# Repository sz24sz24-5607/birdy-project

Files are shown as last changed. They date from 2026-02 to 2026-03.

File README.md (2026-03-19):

<p align="center">
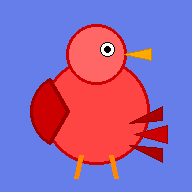
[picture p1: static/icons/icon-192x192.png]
Birdy Logo
  
</p>

<h1 align="center">Birdy - Smart Bird Feeder</h1>

<p align="center">
  <strong>AI-powered bird species identification on a Raspberry Pi 5</strong>
</p>

<p align="center">
  <a href="#features">Features</a> &bull;
  <a href="#hardware">Hardware</a> &bull;
  <a href="#architecture">Architecture</a> &bull;
  <a href="#installation">Installation</a> &bull;
  <a href="#configuration">Configuration</a> &bull;
  <a href="#home-assistant">Home Assistant</a>
</p>

---

Birdy turns a regular bird feeder into an intelligent monitoring station. A PIR sensor detects motion, triggers a camera recording, and a TensorFlow Lite model identifies the bird species in real time - all running locally on a Raspberry Pi 5 with no cloud dependency.

## Features

- **Real-time Bird Detection** - PIR motion sensor triggers dynamic video recording (up to 30s) at 720p/15fps
- **ML Species Identification** - TensorFlow Lite classifier identifies bird species in ~50-100ms
- **Regional Species Filter** - Swiss Mittelland allowlist (151 species) prevents implausible detections like Cardinals or Cockatoos
- **Web Dashboard** - Responsive Django web app with live stats, photo gallery, and video playback
- **Home Assistant Integration** - MQTT auto-discovery for feed weight, species, and visit counters
- **Weight Monitoring** - HX711 load cell tracks food level with automatic drift compensation
- **PWA Support** - Install as a native app on your phone
- **USB Media Storage** - Photos and videos stored on external USB drive
- **Statistics** - Daily, monthly, and yearly visit tracking per species

## Hardware

| Component | Model | GPIO |
| --- | --- | --- |
| Single Board Computer | Raspberry Pi 5 | - |
| Camera | Pi Camera Module | CSI |
| Motion Sensor | HC-SR501 PIR | GPIO 17 |
| Weight Sensor | HX711 + Load Cell | GPIO 5 (DT), GPIO 6 (SCK) |
| Storage | USB Drive mounted at `/mnt/birdy_storage` | USB |

## Architecture

```
PIR Trigger ──> Video Recording ──> Frame Extraction ──> ML Classification
   (GPIO 17)     (rpicam-vid)         (ffmpeg)           (TF Lite)
                                                             │
                    ┌────────────────────────────────────────┘
                    ▼
              ┌──────────┐     ┌──────────────┐     ┌─────────────┐
              │PostgreSQL │     │ MQTT Publish  │     │  Web Dashboard│
              │  Storage  │     │Home Assistant │     │  (Gunicorn)   │
              └──────────┘     └──────────────┘     └─────────────┘
```

### Tech Stack

| Layer | Technology |
| --- | --- |
| Web Framework | Django 5.0, Django REST Framework |
| Database | PostgreSQL 12 |
| Task Queue | Celery + Redis |
| ML Inference | TensorFlow Lite (iNaturalist bird model) |
| Video Encoding  | H.264 via rpicam-vid |
| WSGI Server | Gunicorn |
| Home Automation | MQTT (paho-mqtt) |
| Camera | picamera2 |

## Installation

### Prerequisites

- Raspberry Pi 5 with Raspberry Pi OS (64-bit)
- Python 3.13+
- PostgreSQL, Redis
- Pi Camera Module, HC-SR501 PIR sensor, HX711 weight sensor

### Setup

```bash
# Clone the repository
git clone https://github.com/sz24sz24-5607/birdy-project.git
cd birdy-project

# Create virtual environment
python3 -m venv venv
source venv/bin/activate

# Install dependencies
pip install -r requirements.txt

# Configure environment
cp .env.example .env
# Edit .env with your credentials

# Setup database
python manage.py migrate
python manage.py createsuperuser

# Collect static files
python manage.py collectstatic

# Calibrate weight sensor
python manage.py calibrate_weight
```

### Running

**Development:**
```bash
./start_dev.sh
```

**Production (systemd):**
```bash
# Copy service files
sudo cp systemd/*.service /etc/systemd/system/
sudo systemctl daemon-reload

# Enable and start all services
sudo systemctl enable --now birdy-gunicorn
sudo systemctl enable --now birdy-celery-worker
sudo systemctl enable --now birdy-celery-beat
sudo systemctl enable --now birdy-detection
```

## Configuration

All settings are in `birdy_config/settings.py`. Key parameters:

```python
BIRDY_SETTINGS = {
    'CAMERA_RESOLUTION': (1280, 720),
    'CAMERA_FRAMERATE': 15,
    'RECORDING_DURATION_SECONDS': 4,         # Fallback static duration
    'MAX_RECORDING_DURATION_SECONDS': 30,    # Dynamic recording max
    'PIR_ABSENCE_THRESHOLD_SECONDS': 3,      # PIR LOW for Xs → stop recording
    'VISIT_CONTINUATION_WINDOW_SECONDS': 300, # Same species within 5min = same visit
    'MIN_CONFIDENCE_THRESHOLD': 0.7,         # Display threshold
    'MIN_CONFIDENCE_SPECIES': 0.5,           # Valid visit threshold
    'BIRD_DETECTOR_ENABLED': True,           # SSD MobileNet V2 size/position filter
    'MIN_BIRD_COVERAGE': 0.05,               # Min bird bbox area (5% of frame)
}
```

Sensitive values (DB password, MQTT credentials, secret key) are loaded from `.env`.

## Home Assistant

Birdy publishes to MQTT with Home Assistant auto-discovery:

| Entity | Topic | Description |
| --- | --- | --- |
| Feed Weight | `birdy/feed/weight` | Current food weight (grams) |
| Bird Detected | `birdy/bird/detected` | Binary motion sensor |
| Last Species  | `birdy/bird/species`  | Last identified species |
| Visits Today  | `birdy/stats/today` | Daily visit counter |

## Detection Pipeline

1. PIR sensor triggers on motion
2. Camera records video dynamically (H.264, 720p): stops when PIR LOW for 3s, max 30s
3. Frames extracted proportionally via ffmpeg (2fps, min 8): e.g. 15s → 30 frames
4. Bird Size/Position Filter (SSD MobileNet V2 COCO): frames without a sufficiently large
   bird in the feeder area are discarded (fail-open: if all rejected, all frames are kept)
5. TensorFlow Lite classifies remaining frames (~50-100ms per frame)
   - Only species from `ml_models/swiss_midland_allowlist.txt` are considered (151 Swiss Mittelland species)
   - The species with the highest score among allowed species wins per frame
6. Frame with highest non-background confidence is selected as the best frame
7. If no valid bird detected (confidence < 50% or all frames = background): video deleted, no DB entry
8. Visit deduplication: same species within 5 minutes → `is_new_visit=False`, statistics not inflated
9. Results stored in PostgreSQL with best photo + video
10. MQTT notification sent to Home Assistant
11. Web dashboard updates automatically

### Regional Species Filter

The global iNaturalist model covers ~964 bird species worldwide. Without filtering, implausible
species were regularly detected (Northern Cardinal, Monk Parakeet, Galah, Kea, etc.).

The allowlist `ml_models/swiss_midland_allowlist.txt` restricts detections to **151 species**
plausible for the Swiss Mittelland — resident birds, common migrants, and waterbirds. The file
uses scientific names and can be freely extended. Restart `birdy-detection` after changes.

| Allowlist groups  | Examples |
| --- | --- |
| Songbirds | Robin, Blackbird, Tits, Finches, Buntings, Sparrows |
| Swallows / Swifts | Barn Swallow, House Martin, Common Swift |
| Woodpeckers | Great Spotted, Green Woodpecker |
| Pigeons | Wood Pigeon, Collared Dove |
| Owls | Barn Owl, Little Owl, Long-eared Owl |
| Raptors | Buzzard, Kestrel, Sparrowhawk, Red Kite |
| Corvids | Magpie, Jay, Jackdaw, Rook, Raven |
| Waterbirds | Mallard, Coot, Grey Heron, Cormorant |
| Swans & Geese | Mute Swan, Greylag Goose, Egyptian Goose |

## Mechanical Construction

The birdhouse enclosure is a hybrid construction with 3D-printed and CNC-milled parts. All source files and manufacturing data are in the `mechanic/` folder.

<p align="center">
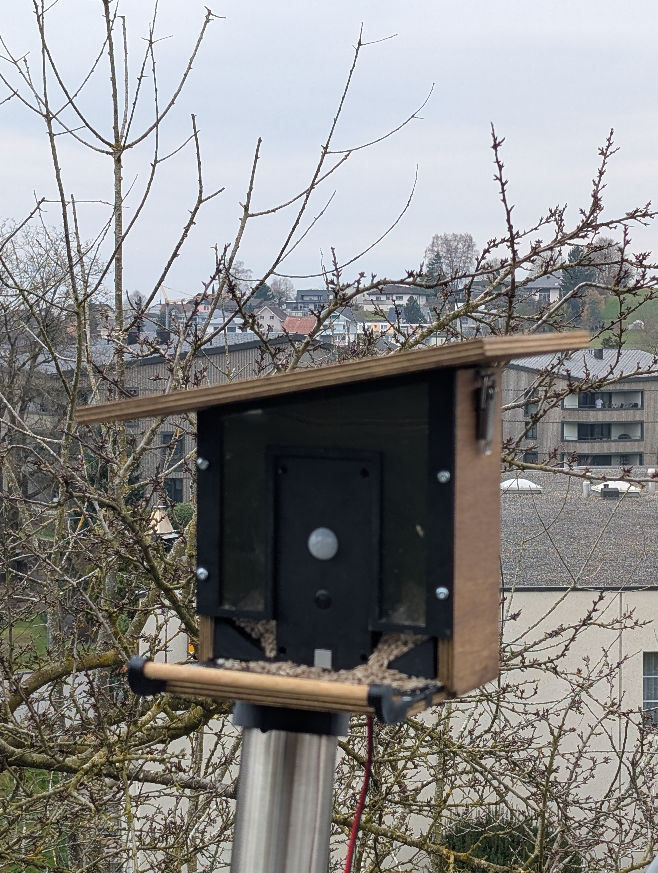
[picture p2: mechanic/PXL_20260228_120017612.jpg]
Finished Birdy birdhouse mounted on a pole
  
</p>

### 3D-Printed Parts (FDM)

| File | Description |
| --- | --- |
| `box_top.stl` / `box_bottom.stl` | Electronics enclosure (Raspberry Pi, camera) |
| `feeder_plate.stl` | Seed tray |
| `frame_left.stl` / `frame_right.stl` | Side frames |
| `bar_left.stl` / `bar_right.stl` | Mounting bars |
| `pole_mount.stl` / `pole_mount_2.stl` | Pole/post mounting bracket |
| `weight_main.stl` / `weight_left.stl` / `weight_right.stl` | Weight sensor housing |
| `konstruktion.skp` | SketchUp source file (full assembly) |

### CNC-Milled Parts (Wood) – `mechanic/mill/`

| File | Description |
| --- | --- |
| `back.stl` / `base.stl` / `left.stl` / `right.stl` | Wooden wall panels |
| `roof.stl` / `window.stl` | Roof and window panel |
| `*.E12` | Estlcam CNC project files |
| `m_*.gcode` | G-code toolpaths for CNC mill |

## Project Structure

```
birdy_project/
├── birdy_config/        # Django project settings & main views
├── sensors/             # Sensor models & management commands
├── species/             # Bird species models & statistics
├── media_manager/       # Photo & video models
├── homeassistant/       # MQTT client & HA integration
├── api/                 # REST API (DRF)
├── hardware/            # Camera, PIR, weight sensor drivers
├── services/            # Bird detection service
├── ml_models/           # TFLite model & label files
├── templates/           # Django HTML templates
├── static/              # CSS, icons, PWA manifest
├── systemd/             # Service files for production
└── mechanic/            # Birdhouse construction files (STL, SketchUp, G-code)
    └── mill/            # CNC milling files (Estlcam, G-code)
```

## Example Detections

<p align="center">
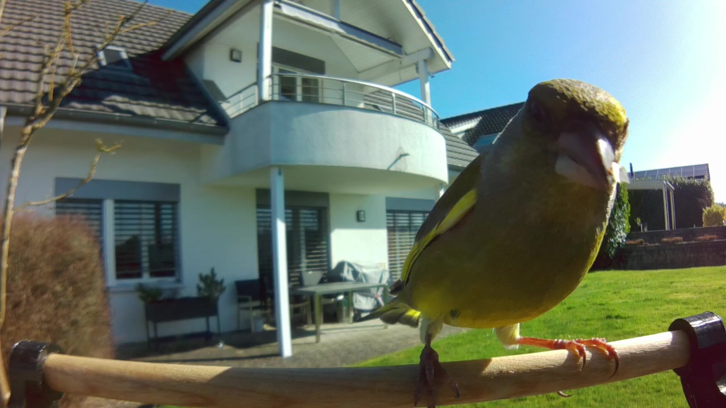
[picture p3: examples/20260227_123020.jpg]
Grünfink (European Greenfinch)
  
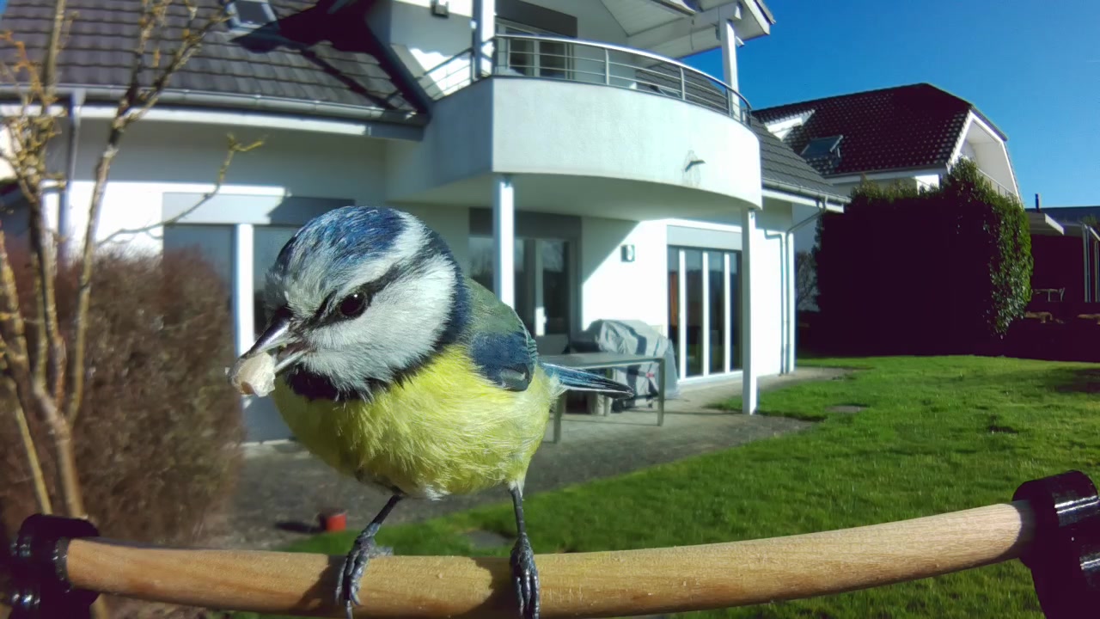
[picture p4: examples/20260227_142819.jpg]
Blaumeise (Blue Tit)
  
</p>
<p align="center">
  <em>Left: European Greenfinch &nbsp;|&nbsp; Right: Blue Tit picking up a seed</em>
</p>

## License

This project is open source. Feel free to build your own smart bird feeder!

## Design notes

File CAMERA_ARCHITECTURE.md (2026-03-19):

# Kamera-Architektur - Wichtige Hinweise

## Problem: Kamera-Zugriff über Prozessgrenzen

### Ursprüngliches Design (NICHT FUNKTIONSFÄHIG)
1. `start_birdy` initialisiert Kamera
2. PIR Motion Event triggert → `process_bird_detection.delay()` (Celery Task)
3. Celery Worker führt Task aus → **FEHLER**: Kamera nicht verfügbar!

### Warum das nicht funktioniert
- **Singleton funktioniert nur pro Prozess**: `_camera_worker_instance` ist in jedem Python-Prozess separate Variable
- **start_birdy Prozess**: Hat Camera Worker mit Kamera-Zugriff
- **Celery Worker Prozess**: Erstellt NEUEN Camera Worker ohne Kamera-Zugriff
- **Fehler**: `Camera not initialized (should be initialized by start_birdy)`

## Aktuelle Lösung: Thread-basierte Verarbeitung mit Recording Lock

### Architektur
1. `start_birdy` initialisiert Kamera, PIR-Sensor und Detection Service
2. PIR Motion Event triggert → `detection_service.handle_motion_detected(pir_event)`
3. `handle_motion_detected()` prüft `_recording_lock`: falls gesperrt → PIR-Trigger ignorieren
4. Falls frei → **Detection-Thread starten** (daemon=False, läuft bis zum Ende)
5. Verarbeitung läuft im **gleichen Prozess** wie start_birdy → Kamera verfügbar ✓
6. Thread belegt `_recording_lock` für gesamte Aufnahme + Klassifikation

### Code
In `services/bird_detection.py`:
```python
def handle_motion_detected(self, pir_event):
    # Wenn gerade eine Aufnahme läuft: PIR-Trigger ignorieren
    if self._recording_lock.locked():
        logger.debug("Recording already in progress – PIR trigger ignored")
        return

    # Detection in separatem Thread (PIR-Monitoring blockiert nicht)
    detection_thread = threading.Thread(
        target=self.process_detection,
        args=(pir_event.id,),
        daemon=False,
        name=f"BirdDetection-{pir_event.id}"
    )
    detection_thread.start()
```

### Vorteile
- ✓ Kamera-Zugriff funktioniert
- ✓ PIR-Monitoring wird während der Aufnahme **nicht blockiert**
- ✓ `_recording_lock` verhindert parallele Aufnahmen sauber
- ✓ Neue PIR-Trigger während laufender Aufnahme werden ignoriert
- ✓ Passt zur Hardware-Einschränkung (nur 1 Kamera)

### Dynamische Aufnahmedauer

Statt fixer 4s nutzt `record_video_dynamic()` den PIR-Status:
- Startet rpicam-vid als Hintergrundprozess (`subprocess.Popen`)
- Überwacht PIR alle 200ms: PIR LOW für ≥ `PIR_ABSENCE_THRESHOLD_SECONDS` (3s) → Aufnahme stoppen
- Sicherheitsnetz: max. `MAX_RECORDING_DURATION_SECONDS` (30s)
- Gibt `(mp4_path, actual_duration_seconds)` zurück

### Recording Lock Flow

```
PIR HIGH → handle_motion_detected()
  → _recording_lock.locked()? → TRUE  → Trigger ignoriert (Aufnahme läuft bereits)
                               → FALSE → Detection-Thread starten

Detection-Thread:
  with _recording_lock:          ← Lock belegen
    record_video_dynamic()       ← PIR überwachen, dynamisch stoppen (bis 30s)
    extract_candidate_frames()   ← Proportional (2fps, min 8 Frames)
    BirdSizeDetector filter      ← Frames ohne vollständigen Vogel verwerfen
    Alle Frames klassifizieren   ← Bestes Frame wählen
    BirdDetection speichern      ← is_new_visit Deduplication
                                 ← Lock freigeben → bereit für nächsten Besuch
```

## Celery Task Status

Der Celery Task `process_bird_detection` existiert noch, wird aber **NICHT verwendet**:
```python
@shared_task
def process_bird_detection(pir_event_id):
    """
    HINWEIS: Dieser Task wird aktuell NICHT verwendet!
    Grund: Kamera läuft nur in start_birdy Prozess, Celery Worker hat keinen Zugriff.
    """
    logger.warning("process_bird_detection task called - but detection should run in start_birdy!")
    pass
```

Der Task bleibt für potenzielle zukünftige Verwendung (z.B. Re-Processing von bereits aufgenommenen Videos).

## Celery Worker Konfiguration

Die `bird_detection` Queue-Konfiguration bleibt bestehen:
- `celery.py`: Task-Routing für `services.bird_detection.process_bird_detection`
- `settings.py`: Queue-Definition mit `bird_detection` und `default`

**Diese Konfiguration schadet nicht**, sie ist einfach inaktiv, da der Task nicht aufgerufen wird.

## Alternative Lösungen (NICHT implementiert)

### Option 1: Shared Camera Service via IPC
- Camera Worker als eigenständiger Service (z.B. Socket/Redis)
- Alle Prozesse kommunizieren über IPC
- **Zu komplex** für dieses Projekt

### Option 2: Video-Aufnahme und Processing trennen
- start_birdy: Nur Video aufnehmen, in DB speichern
- Celery Task: Nur Frame-Extraktion + Classification
- **Problem**: Erfordert Umstrukturierung, mehr Arbeit

### Option 3: Multiprocessing Queue/Pipe
- Camera Worker teilt Queue mit Celery Worker
- **Problem**: Celery und start_birdy sind separate Prozess-Bäume

## Was zu tun ist

### Beim Starten des Systems
```bash
# 1. Redis
redis-server &

# 2. Django
python manage.py runserver &

# 3. Celery Worker (für Sensoren, MQTT, Statistiken)
celery -A birdy_config worker -Q default --loglevel=info &

# 4. Celery Beat
celery -A birdy_config beat --loglevel=info &

# 5. start_birdy (PIR + Camera + Detection)
python manage.py start_birdy
```

**WICHTIG**: Du brauchst **KEINEN** separaten Worker für die `bird_detection` Queue, da diese nicht verwendet wird!

### Bei Debugging
Wenn du Fehler wie `Camera not initialized` siehst:
1. Prüfe ob start_birdy läuft
2. Prüfe ob Kamera in start_birdy initialisiert wurde
3. Prüfe ob `handle_motion_detected()` den Detection-Thread startet (nicht `.delay()`)

## Zusammenfassung

**Bird Detection läuft in einem Thread im start_birdy-Prozess, NICHT als Celery Task.**

- `_recording_lock` verhindert parallele Aufnahmen
- `record_video_dynamic()` nimmt auf solange der Vogel da ist (PIR-basiert, max. 30s)
- PIR-Monitoring wird während der Aufnahme nicht blockiert
- Sequentielle Verarbeitung (ein Vogel zur Zeit) ist korrekt für eine einzelne Kamera

Die Celery Queue-Konfiguration bleibt für potenzielle zukünftige Erweiterungen bestehen.

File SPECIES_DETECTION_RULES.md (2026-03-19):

# Spezies-Detektion Regeln

## Gültige Besuche

Ein Detection Event wird nur dann als **gültiger Besuch** gezählt, wenn:

1. **Confidence >= 50%** (`MIN_CONFIDENCE_SPECIES` in settings.py)
2. **Spezies ist NICHT "background"** (letzte Zeile in labels.txt)
3. **Spezies ist im Swiss Mittelland Allowlist** (`ml_models/swiss_midland_allowlist.txt`)

## Konfiguration

In `birdy_config/settings.py`:

```python
BIRDY_SETTINGS = {
    ...
    'MIN_CONFIDENCE_THRESHOLD': 0.7,      # Schwellwert für Classifier (70%)
    'MIN_CONFIDENCE_SPECIES': 0.5,        # Minimum für gültigen Besuch (50%)
    ...
}
```

### Parameter-Erklärung:

- **`MIN_CONFIDENCE_THRESHOLD`** (70%): Interner Classifier-Schwellwert, wird von `is_confident_detection()` genutzt
- **`MIN_CONFIDENCE_SPECIES`** (50%): Schwellwert für gültige Besuche - bestimmt ob eine Detection als Besuch zählt

## Swiss Mittelland Regionaler Filter

Das verwendete ML-Modell (iNaturalist) kennt ~964 Vogelarten weltweit. Ohne Filter wurden
regelmässig unplausible Arten erkannt, z.B. **Rotkardinal** (Nordamerika), **Mönchssittich**
(Südamerika) oder **Rosakakadu** (Australien).

### Funktionsweise

Beim Start lädt der Classifier die Datei `ml_models/swiss_midland_allowlist.txt` mit
wissenschaftlichen Namen der im Schweizer Mittelland vorkommenden Arten. Nur diese Arten
werden bei der Klassifikation berücksichtigt. Der **höchste Score unter den erlaubten Arten**
gewinnt. `background` ist immer erlaubt, damit Nicht-Vogel-Frames korrekt erkannt werden.

```
Log-Meldung beim Start:
  Swiss Mittelland filter active: 152 allowed classes (151 species + background)
```

### Allowlist verwalten

Die Datei `ml_models/swiss_midland_allowlist.txt` enthält wissenschaftliche Namen
(eine Art pro Zeile, `#`-Zeilen werden ignoriert):

```
# Finken / Finches
Fringilla coelebs
Chloris chloris
Carduelis carduelis
...
```

**Arten hinzufügen/entfernen:** Datei editieren, dann `birdy-detection` neu starten.

### Erlaubte Artengruppen (151 Arten)

| Gruppe | Beispiele |
|---|---|
| Singvögel | Rotkehlchen, Amsel, Meisen, Finken, Ammern, Spatzen, Stelzen |
| Schwalben / Segler | Rauchschwalbe, Mehlschwalbe, Mauersegler |
| Spechte | Buntspecht, Grünspecht |
| Tauben | Ringeltaube, Türkentaube, Straßentaube |
| Eulen | Schleiereule, Steinkauz, Waldohreule |
| Greifvögel | Bussard, Turmfalke, Sperber, Rotmilan |
| Rabenvögel | Amsel, Elster, Eichelhäher, Dohle, Saatkrähe |
| Wasservögel | Stockente, Blässhuhn, Graureiher, Kormoran |
| Schwäne & Gänse | Höckerschwan, Graugans, Nilgans |
| Limikolen | Kiebitz, Bekassine, Flussuferläufer |

### Beispiel aus den Logs (27. Feb 2026)

**Ohne Filter: Mönchssittich gespeichert (falsch)**
```
Frame 2: Haussperling    82%   ← wäre korrekt
Frame 7: Mönchssittich  136%   ← gewann, weil global höchster Score
→ Detection saved: Mönchssittich  ✗
```

**Mit Filter: Haussperling gespeichert (korrekt)**
```
Frame 2: Haussperling    82%   ← höchster Score unter Schweizer Arten
Frame 7: Mönchssittich  136%   ← gefiltert (nicht in Allowlist)
→ Detection saved: Haussperling  ✓
```

**Mit Filter: Falsch-Positiv verhindert**
```
Frame 5: Schwarzkopfmeise  61%  ← gefiltert (nordamerikanisch)
Frame 3: Kohlmeise         40%  ← Schweizer Kandidat, aber 40% < 50%
→ Not a valid visit          ✓
```

## Implementierung

### 1. Detection Workflow (`services/bird_detection.py`)

**Dynamische Videoaufnahme:** rpicam-vid läuft solange der PIR HIGH ist, maximal 30s.
Die tatsächliche Aufnahmedauer bestimmt die Anzahl extrahierter Frames.

**Proportionale Frame-Extraktion:** 2 Frames pro Sekunde, mindestens 8:
- 4s-Video → 8 Frames
- 15s-Video → 30 Frames
- 30s-Video → 60 Frames

**BirdSizeDetector-Filter (SSD MobileNet V2 COCO):** Frames ohne erkennbaren Vogel
oder mit Vogel ausserhalb des ROI werden verworfen. Fail-Open: Falls alle Frames gefiltert
werden, werden alle Frames als Fallback verwendet.

```python
# Bird Size & Position Filter
if bird_detector and bird_detector.is_initialized:
    filtered = [f for f in candidate_frames if bird_detector.is_valid_bird_frame(f)]
    if filtered:
        candidate_frames = filtered  # Nur Frames mit vollständigem Vogel

# Alle (gefilterten) Frames klassifizieren
for frame_path in candidate_frames:
    result = classifier.classify(frame_path, top_k=5)
    if not is_background and confidence > best_confidence:
        best_confidence = confidence
        best_frame = frame_path

# Bestes Frame bewerten
if best_frame is not None and best_confidence >= min_confidence:
    is_valid_visit = True
    species = BirdSpecies.objects.get_or_create(...)
```

**Ergebnis:**
- Kein gültiger Frame → Video und Temp-Frames werden gelöscht, **kein DB-Eintrag**
- Gültiger Frame → bestes Frame wird als Photo gespeichert, DB-Einträge werden erstellt

### 2. Visit-Deduplication (`is_new_visit`)

Ein langer Vogelbesuch kann mehrere Detection-Zyklen erzeugen (Aufnahme endet, Vogel
bleibt). Um Statistiken nicht aufzublähen, wird jede Detection als `is_new_visit=True`
oder `is_new_visit=False` markiert:

- **Neuer Besuch** (`is_new_visit=True`): letzte Detection der Spezies ist entweder
  unbekannt oder länger als `VISIT_CONTINUATION_WINDOW_SECONDS` (300s) her
- **Fortsetzung** (`is_new_visit=False`): gleiche Spezies innerhalb von 5 Minuten zuletzt gesehen

### 3. Statistiken (`species/models.py`)

```python
# Statistiken zählen nur echte neue Besuche
DailyStatistics.objects.filter(..., is_new_visit=True)
```

**Ergebnis:** Nur `is_new_visit=True`-Detections fliessen in Tages-, Monats- und
Jahresstatistiken ein. Fortsetzungen eines langen Besuchs werden nicht doppelt gezählt.

### 3. Visit Counts (MQTT, Dashboard)

```python
# homeassistant/tasks.py und homeassistant/mqtt_client.py
total_visits = BirdDetection.objects.filter(
    timestamp__date=today,
    processed=True,
    species__isnull=False  # NUR gültige Besuche
).count()
```

**Ergebnis:** Visit Counter zeigt nur gültige Besuche an. Da ungültige Detections nie in der DB landen, wird hier nur über tatsächliche BirdDetection-Einträge gezählt.

## Beispiele

### Beispiel 1: Hohe Confidence, echte Spezies
- **Bestes Frame:** "Parus major" mit 85% Confidence (Frame 3 von 8)
- **Gültiger Besuch?** ✅ JA
- **Log:** `Best frame: frame_03.jpg → Parus major (85.0%) [512ms total]`
- **Ergebnis:** Bestes Frame gespeichert, Spezies in DB, Statistik aktualisiert

### Beispiel 2: Niedrige Confidence über alle Frames
- **Bestes Frame:** "Parus major" mit 35% Confidence
- **Gültiger Besuch?** ❌ NEIN
- **Grund:** 35% < 50% (kein Frame erreicht Schwellwert)
- **Log:** `Not a valid visit: best confidence too low (35.0% < 50.0%)`
- **Ergebnis:** Video gelöscht, kein DB-Eintrag

### Beispiel 3: Alle Frames = Background
- **Bestes Frame:** alle Frames als "background" klassifiziert
- **Gültiger Besuch?** ❌ NEIN
- **Grund:** "background" wird immer übersprungen
- **Log:** `Not a valid visit: no valid (non-background) frame found`
- **Ergebnis:** Video gelöscht, kein DB-Eintrag

### Beispiel 4: Grenzfall
- **Bestes Frame:** "Parus major" mit 50% Confidence
- **Gültiger Besuch?** ✅ JA
- **Grund:** 50% >= 50% UND nicht "background"
- **Ergebnis:** Bestes Frame gespeichert, Statistik aktualisiert

## Auswirkungen auf Daten

### Was wird gespeichert?

**Nur bei gültigen Besuchen** (confidence >= 50%, kein background):
- Video (MP4) auf USB-Storage
- Bestes Frame (JPG) auf USB-Storage
- `Video`-, `Photo`-, `BirdDetection`-DB-Einträge
- `BirdDetection.species` gesetzt
- Eintrag in `DailyStatistics`
- Zählt in Visit Counters (Dashboard, MQTT)

**Bei ungültigen Detections** (background, zu niedrige Konfidenz):
- Video und Temp-Frames werden sofort gelöscht
- **Kein DB-Eintrag** wird erstellt

### Datenbank Queries für Analyse

```python
# Alle Detections (auch ungültige)
all_detections = BirdDetection.objects.filter(processed=True)

# Nur gültige Besuche
valid_visits = BirdDetection.objects.filter(
    processed=True,
    species__isnull=False
)

# Ungültige Detections (background oder low confidence)
invalid_detections = BirdDetection.objects.filter(
    processed=True,
    species__isnull=True
)

# Confidence-Verteilung analysieren
from django.db.models import Avg, Count
BirdDetection.objects.values('species__isnull').annotate(
    avg_conf=Avg('confidence'),
    count=Count('id')
)
```

## Anpassung der Schwellwerte

Um den Schwellwert zu ändern, editiere `birdy_config/settings.py`:

```python
'MIN_CONFIDENCE_SPECIES': 0.6,  # Erhöhe auf 60%
```

**Nach Änderung:**
1. Starte `start_birdy` neu
2. Neue Detections nutzen den neuen Schwellwert
3. Alte Detections bleiben unverändert (bereits in DB)

## Troubleshooting

### Problem: Zu viele ungültige Detections

**Ursache:** Background wird häufig erkannt (z.B. bei schlechtem Licht)

**Lösung:**
- Verbessere Beleuchtung am Futterhaus
- Positioniere Kamera besser
- Oder: Erhöhe `MIN_CONFIDENCE_SPECIES` auf 60-70%

### Problem: Zu wenige Besuche

**Ursache:** Schwellwert zu hoch, echte Vögel werden nicht gezählt

**Lösung:**
- Senke `MIN_CONFIDENCE_SPECIES` auf 40%
- Prüfe ungültige Detections:
  ```python
  BirdDetection.objects.filter(
      species__isnull=True,
      confidence__gte=0.4
  ).order_by('-confidence')
  ```

### Problem: Background wird als Spezies gezählt

**Ursache:** Code-Bug oder labels.txt hat "background" nicht als letzte Zeile

**Lösung:**
- Prüfe `ml_models/labels.txt` - letzte Zeile muss "background" sein
- Prüfe Code in `services/bird_detection.py` Zeile 158:
  ```python
  is_background = species_label.lower() == 'background'
  ```

### Problem: Art in den Logs erkannt aber nicht gespeichert

**Ursache:** Art ist nicht im Swiss Mittelland Allowlist

**Prüfen:**
```bash
grep "Swiss Mittelland" /home/pi/birdy_project/logs/birdy.log | tail -1
# Swiss Mittelland filter active: 152 allowed classes (151 species + background)
```

**Lösung:** Wissenschaftlichen Namen in `ml_models/swiss_midland_allowlist.txt` eintragen,
dann `sudo systemctl restart birdy-detection`.

### Problem: Filter lädt nicht (labels_en.txt fehlt)

**Ursache:** `labels_en.txt` fehlt im `ml_models/`-Ordner

**Lösung:** Ohne `labels_en.txt` kann kein Mapping von wissenschaftlichen Namen zu Model-Indices
aufgebaut werden → Filter wird deaktiviert (alle Arten erlaubt, Warning im Log).

## Zusammenfassung

**Gültiger Besuch = bestes Frame aus proportional vielen Kandidaten (2fps, min. 8) erfüllt alle Bedingungen:**
1. Confidence >= 50%
2. Kein "background"
3. Art ist im Swiss Mittelland Allowlist (`ml_models/swiss_midland_allowlist.txt`)

**Zusätzliche Filter:**
- BirdSizeDetector (SSD MobileNet V2): Frames mit zu kleinem Vogel oder ausserhalb ROI werden verworfen
- `is_new_visit`: Statistiken zählen nur echte neue Besuche (Deduplication via 5-Min-Fenster)

Ungültige Detections werden **nicht** in die DB gespeichert:
- ❌ Kein DB-Eintrag
- ❌ Kein Video gespeichert
- ❌ Kein Foto gespeichert
- ❌ Keine Statistik
- ❌ Keine MQTT-Benachrichtigung

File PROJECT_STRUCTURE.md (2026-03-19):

# Birdy Project Structure

Aufgeräumt am: $(date +%Y-%m-%d)

## Aktive Verzeichnisse

### Core Application
```
birdy_project/
├── birdy_config/         # Django settings, Celery config, URLs
├── hardware/             # Hardware interfaces (PIR, Camera, Weight)
├── sensors/              # Sensor models, management commands
├── services/             # Bird detection service
├── species/              # Species detection, classification
├── media_manager/        # Photo/Video management
├── homeassistant/        # Home Assistant MQTT integration
├── api/                  # REST API (optional)
└── manage.py            # Django management
```

### Configuration & Deployment
```
├── systemd/              # Systemd service files for production
├── logs/                 # Application logs
├── media/                # Django media files
├── static/               # Static files
├── staticfiles/          # Collected static files
└── venv/                 # Python virtual environment
```

### ML & Models
```
└── ml_models/            # TensorFlow Lite models for bird classification
```

## Aktive Scripts

### Development & Operations
- **start_dev.sh** - Start development environment (Redis, Celery, Django, Birdy)
- **stop_dev.sh** - Stop all services
- **restart_birdy.sh** - Restart Birdy detection system

### Backup & Recovery
- **backup_to_nas.sh** - Backup project to NAS
- **restore_from_nas.sh** - Restore project from NAS backup

### Analysis
- **analyze_pir_pattern.py** - Analyze PIR trigger patterns from logs

### Maintenance
- **move_to_archive.sh** - Move unused files to archive (already executed)

## Aktive Dokumentation

### Setup & Configuration
- **GIT_SETUP.md** - Git und NAS Backup Setup Anleitung
- **QUICK_START_BACKUP.md** - Schnelleinstieg Backup
- **PRODUCTION_SETUP.md** - Production Deployment Guide
- **MQTT_SETUP.md** - Home Assistant MQTT Integration

### Architecture & Development
- **CAMERA_ARCHITECTURE.md** - Camera System Architektur
- **SPECIES_DETECTION_RULES.md** - Species Classification Regeln
- **LGPIO_MIGRATION.md** - Migration zu native lgpio (Raspberry Pi 5)

### Troubleshooting & Bugfixes
- **PIR_TROUBLESHOOTING.md** - PIR Debugging Guide
- **BUGFIX_PIR_8S_DELAY.md** - Dokumentation des 8-Sekunden Delay Bugfix

## Archivierte Dateien

Verschoben nach `birdy_archive/`:

### Dokumentation (veraltet/redundant)
- CELERY_WORKER_SETUP.md → Ersetzt durch PRODUCTION_SETUP.md
- PIR_DEBUGGING_PI5.md → Info jetzt in PIR_TROUBLESHOOTING.md
- GPIO_MONITORING.md → Nicht mehr relevant mit native lgpio
- RASPBERRY_PI5_GPIO.md → Covered in LGPIO_MIGRATION.md

### Scripts (nicht mehr benötigt)
- monitor_pir_gpio.py → Funktioniert nicht auf Pi 5 mit claimed pins
- monitor_pir_sysfs.py → sysfs nicht verfügbar auf Pi 5
- monitor_pir_direct.py → Pin Konflikt mit Hauptapp
- monitor_pir.sh → Wrapper für obige Scripts

### Duplikate
- settings.py → Duplikat (echte Datei: birdy_config/settings.py)
- check_status.sh → Funktionalität in start_dev.sh

### Build Artifacts (können gelöscht werden)
- tensorflow_src/ (1.8 GB)
- tflite_build/ (2.0 GB)
- venv_old/ (1.8 GB)

**Speicherplatz freigeben:**
```bash
rm -rf birdy_archive/tensorflow_src
rm -rf birdy_archive/tflite_build
rm -rf birdy_archive/venv_old
# → Spart ~5.6 GB!
```

## Wichtige Dateien

### Configuration
- `birdy_config/settings.py` - Django Settings
- `birdy_config/celery.py` - Celery Configuration
- `.gitignore` - Git ignore patterns
- `requirements.txt` - Python dependencies

### Hardware Layer
- `hardware/pir_sensor.py` - PIR Motion Sensor (native lgpio)
- `hardware/camera.py` - Picamera2 + rpicam-vid
- `hardware/weight_sensor.py` - HX711 Weight Sensor

### Detection Workflow
- `sensors/management/commands/start_birdy.py` - Main detection loop
- `services/bird_detection.py` - Detection workflow orchestration
- `ml_models/bird_classifier.py` - TensorFlow Lite classification (iNaturalist)
- `ml_models/bird_detector.py` - Bird size/position filter (SSD MobileNet V2 COCO)
- `ml_models/bird_detector.tflite` - SSD MobileNet V2 COCO model (6 MB)

## Git Ignore

Folgende Dateien/Ordner werden NICHT gesichert:
- `venv/` - Virtual Environment (wird neu erstellt)
- `logs/` - Log Dateien (zu groß)
- `db.sqlite3` - SQLite Datenbank (wird migriert)
- `media/photos/`, `media/videos/` - Media Files (separat gesichert)
- `__pycache__/`, `*.pyc` - Python Cache
- `birdy_archive/` - Archiv (muss nicht gesichert werden)

Siehe `.gitignore` für vollständige Liste.

## Quick Commands

```bash
# Development
./start_dev.sh          # Start all services
./stop_dev.sh           # Stop all services
./restart_birdy.sh      # Restart detection only

# Backup
./backup_to_nas.sh      # Manual backup to NAS

# Analysis
python3 analyze_pir_pattern.py  # Analyze PIR patterns

# Logs
tail -f logs/birdy.log | grep "PIR:"     # Watch PIR events
tail -f logs/celery_worker.log           # Watch Celery tasks
tail -f logs/django.log                  # Watch Django
```

## Projektgröße

```
Aktiver Code:         ~50 MB
Virtual Environment:  ~500 MB
Logs (variabel):      ~10-100 MB
Media (extern):       Auf USB/NAS
Archive:              ~5.5 GB (kann gelöscht werden)
```

## Nächste Schritte

1. ✅ **Code aufgeräumt** - Archiv erstellt
2. ⏳ **Git initialisieren** - `git init && git add . && git commit -m "Initial commit"`
3. ⏳ **NAS Backup einrichten** - NAS mounten und `./backup_to_nas.sh` testen
4. ⏳ **System testen** - Nach PIR False Triggers überwachen
5. ⏳ **Archive löschen** - `rm -rf birdy_archive/` um 5.6 GB freizugeben (optional)

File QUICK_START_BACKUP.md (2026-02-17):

# Git + NAS Backup - Quick Start

## Sofort loslegen (3 Schritte)

### Schritt 1: NAS einrichten (einmalig)

**Sie brauchen:**
- NAS IP-Adresse
- NAS Share-Name (z.B. "birdy_backup")
- Ggf. Benutzername + Passwort

**Beispiel für Synology/QNAP NAS:**

```bash
# Mount-Point erstellen
sudo mkdir -p /mnt/nas/birdy_backup

# NAS mounten (wählen Sie NFS ODER SMB)

# Option A: NFS (schneller, empfohlen)
sudo mount -t nfs 192.168.1.100:/volume1/birdy_backup /mnt/nas/birdy_backup

# Option B: SMB/CIFS (Windows-kompatibel)
sudo mount -t cifs //192.168.1.100/birdy_backup /mnt/nas/birdy_backup -o username=admin,password=IhrPasswort

# Testen ob es funktioniert
ls /mnt/nas/birdy_backup

# Permanent machen (Mount bleibt nach Neustart)
# Für NFS:
echo "192.168.1.100:/volume1/birdy_backup /mnt/nas/birdy_backup nfs defaults 0 0" | sudo tee -a /etc/fstab

# Für SMB:
echo "//192.168.1.100/birdy_backup /mnt/nas/birdy_backup cifs username=admin,password=IhrPasswort 0 0" | sudo tee -a /etc/fstab
```

**WICHTIG**: Passen Sie an:
- `192.168.1.100` → Ihre NAS IP-Adresse
- `/volume1/birdy_backup` → Ihr NAS Share-Pfad
- `admin` / `IhrPasswort` → Ihre NAS Zugangsdaten

### Schritt 2: Git initialisieren (einmalig)

```bash
cd ~/birdy_project

# Git starten
git init

# Ihre Identität (für Commit-Nachrichten)
git config user.name "Ihr Name"
git config user.email "ihre@email.de"

# Alles hinzufügen
git add .

# Ersten Commit
git commit -m "Initial commit: Birdy Project mit allen Bugfixes"
```

### Schritt 3: Erstes Backup erstellen

```bash
./backup_to_nas.sh
```

**Fertig!** Ihr Code ist jetzt gesichert.

## Tägliche Verwendung

### Code geändert? → Speichern mit Git

```bash
git add .
git commit -m "Kurze Beschreibung was geändert wurde"
```

**Beispiele:**
```bash
git commit -m "PIR Cooldown auf 90s erhöht"
git commit -m "Neue Vogelart Blaumeise hinzugefügt"
git commit -m "Camera Auflösung auf 1920x1080 geändert"
```

### Backup auf NAS

```bash
# Manuell
./backup_to_nas.sh

# Automatisch jeden Tag um 3 Uhr (einmalig einrichten):
crontab -e
# Folgende Zeile einfügen:
0 3 * * * cd /home/pi/birdy_project && ./backup_to_nas.sh >> logs/backup.log 2>&1
```

## Nützliche Befehle

```bash
# Was wurde geändert seit letztem Commit?
git status

# Änderungshistorie ansehen
git log --oneline

# Letzten Commit rückgängig machen
git reset --soft HEAD~1

# Datei auf letzten Stand zurücksetzen
git checkout -- dateiname.py

# Backup-Status prüfen
ls -lh /mnt/nas/birdy_backup/
```

## Im Notfall: System wiederherstellen

```bash
# Projekt von NAS wiederherstellen
./restore_from_nas.sh

# Dann Virtual Environment neu erstellen
python3 -m venv venv
source venv/bin/activate
pip install -r requirements.txt

# System starten
./start_dev.sh
```

## Hilfe

- **Ausführliche Anleitung**: Siehe [GIT_SETUP.md](GIT_SETUP.md)
- **NAS Mount Probleme**: `mount | grep nas` zum Prüfen
- **Git Fragen**: `git status` zeigt immer den aktuellen Zustand

## Was wird gesichert?

✅ Gesamter Code (.py, .sh Dateien)
✅ Konfiguration (settings.py, celery.py, etc.)
✅ Dokumentation (.md Dateien)
✅ Git History (komplette Änderungshistorie)

❌ Logs (zu groß, nicht wichtig)
❌ Videos/Fotos (separat auf USB/NAS)
❌ Virtual Environment (wird neu erstellt)
❌ Datenbank (kann neu migriert werden)

## Häufige Fragen

**Q: Wie oft soll ich committen?**
A: Bei jeder sinnvollen Änderung! Lieber zu oft als zu selten.

**Q: Muss ich vor jedem Backup committen?**
A: Empfohlen, aber nicht zwingend. Backup-Skript warnt wenn uncommitted changes existieren.

**Q: Wie viele Backups werden behalten?**
A: Letzte 30 Tage automatisch. Ältere werden gelöscht.

**Q: Kann ich auch manuell Backups auf USB-Stick machen?**
A: Ja! Einfach `/mnt/nas/birdy_backup/latest` auf USB-Stick kopieren.

**Q: Was wenn NAS offline ist?**
A: Backup schlägt fehl, aber Git funktioniert weiter lokal.

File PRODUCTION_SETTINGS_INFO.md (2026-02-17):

# Production Settings - Wichtige Hinweise

## Erstellte Datei

**birdy_config/settings_production.py** wurde erstellt für Production-Deployment.

## Wichtige Unterschiede zu Development Settings

### Development (settings.py)
- `DEBUG = True` - Zeigt detaillierte Fehler
- `ALLOWED_HOSTS = ['*']` - Akzeptiert alle Hosts
- Console Logging auf DEBUG-Level
- CORS erlaubt alle Origins

### Production (settings_production.py)
- `DEBUG = False` - Keine Fehlerdetails an User
- `ALLOWED_HOSTS` restriktiv - nur definierte Hosts
- Logging auf INFO-Level, separate Error-Logs
- CORS restriktiv - nur erlaubte Origins
- WhiteNoise für Static Files
- Security Headers aktiviert

## ⚠️ VOR Production-Deployment ÄNDERN:

### 1. SECRET_KEY setzen

**WICHTIG:** Generiere einen sicheren SECRET_KEY!

```bash
# SECRET_KEY generieren:
python -c "from django.core.management.utils import get_random_secret_key; print(get_random_secret_key())"

# Dann als Umgebungsvariable setzen:
export DJANGO_SECRET_KEY='your-generated-key-here'

# Oder in /etc/environment eintragen für Persistence:
echo 'DJANGO_SECRET_KEY="your-generated-key-here"' | sudo tee -a /etc/environment
```

### 2. ALLOWED_HOSTS anpassen

Editiere `birdy_config/settings_production.py` Zeile 16-23:

```python
ALLOWED_HOSTS = [
    'localhost',
    '127.0.0.1',
    'raspberrypi',
    'raspberrypi.local',
    '192.168.178.XX',  # Deine Raspberry Pi IP-Adresse
    # 'birdy.example.com',  # Optional: Deine Domain
]
```

### 3. HTTPS aktivieren (optional)

Wenn du HTTPS nutzt, ändere in `settings_production.py`:

```python
CSRF_COOKIE_SECURE = True
SESSION_COOKIE_SECURE = True
```

### 4. CORS Origins anpassen

Falls du API von externen Clients nutzt, passe CORS_ALLOWED_ORIGINS an.

## Verwendung

### Development (lokal testen)
```bash
./start_dev.sh
# Nutzt automatisch settings.py (DEBUG=True)
```

### Production (systemd Services)
```bash
# Services nutzen automatisch settings_production.py
sudo systemctl start birdy-gunicorn
sudo systemctl start birdy-celery-worker
sudo systemctl start birdy-celery-beat
sudo systemctl start birdy-detection
```

## Systemd Services Status

Alle Service-Dateien sind jetzt korrekt konfiguriert:

✅ **birdy-gunicorn.service** - Nutzt settings_production.py
✅ **birdy-celery-worker.service** - Korrekte Queue Konfiguration
✅ **birdy-celery-beat.service** - Periodische Tasks
✅ **birdy-detection.service** - Bird Detection System

## Static Files für Production

```bash
# Sammle Static Files vor Production-Start:
python manage.py collectstatic --noinput --settings=birdy_config.settings_production
```

WhiteNoise serviert dann die Static Files effizient über Gunicorn.

## Logging

Production Logs werden geschrieben nach:
- `logs/birdy.log` - Alle INFO+ Messages
- `logs/birdy_error.log` - Nur ERROR+ Messages
- `logs/gunicorn_access.log` - HTTP Requests
- `logs/gunicorn_error.log` - Gunicorn Errors

## Test Production Settings lokal

```bash
# Mit Production Settings testen:
source venv/bin/activate
DJANGO_SETTINGS_MODULE=birdy_config.settings_production python manage.py check --deploy

# Gunicorn lokal testen:
DJANGO_SETTINGS_MODULE=birdy_config.settings_production gunicorn birdy_config.wsgi:application
```

## Nächste Schritte für Production

1. ✅ SECRET_KEY generieren und setzen
2. ✅ ALLOWED_HOSTS anpassen
3. ⏳ Static Files sammeln (`collectstatic`)
4. ⏳ Systemd Services installieren (siehe PRODUCTION_SETUP.md)
5. ⏳ Services starten und testen

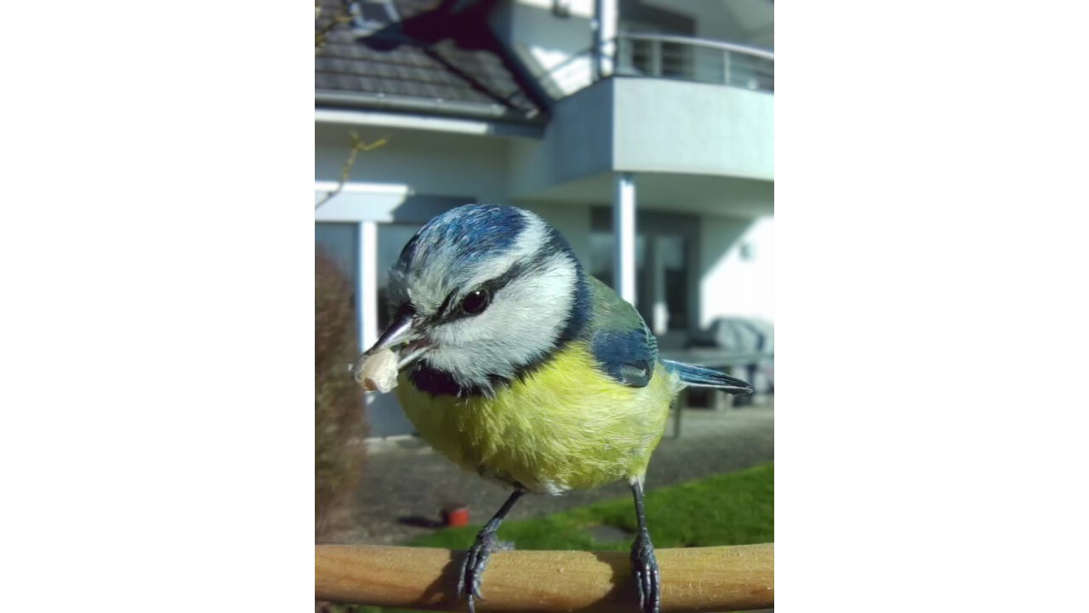
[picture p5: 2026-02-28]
examples/Kohlmeise_bearbeitet.png

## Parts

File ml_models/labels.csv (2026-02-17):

id | name
964 | background
0 | Haemorhous cassinii
1 | Aramus guarauna
2 | Rupornis magnirostris
3 | Cyanocitta cristata
4 | Cyanocitta stelleri
5 | Balearica regulorum
6 | Pyrocephalus rubinus
7 | Recurvirostra americana
8 | Ardeotis kori
9 | Pica nuttalli
10 | Perisoreus canadensis
11 | Antigone canadensis
12 | Parkesia noveboracensis
13 | Ardea herodias occidentalis
14 | Porzana carolina
15 | Anas platyrhynchos diazi
16 | Motacilla cinerea
17 | Empidonax difficilis
18 | Empidonax minimus
19 | Empidonax fulvifrons
20 | Empidonax traillii
21 | Empidonax hammondii
22 | Empidonax occidentalis
23 | Rallus limicola
24 | Grus grus
25 | Quiscalus major
26 | Branta leucopsis
27 | Cyanocorax yucatanicus
28 | Cyanocorax yncas
29 | Oceanites oceanicus
30 | Quiscalus niger
31 | Psilorhinus morio
32 | Megarynchus pitangua
33 | Gallinula tenebrosa
34 | Gallus gallus domesticus
35 | Numida meleagris
36 | Junco hyemalis caniceps
37 | Tyrannus vociferans
38 | Tyrannus tyrannus
39 | Tyrannus forficatus
40 | Tyrannus crassirostris
41 | Tyrannus verticalis
42 | Tyrannus savana
43 | Gallirallus australis
44 | Calocitta formosa
45 | Calocitta colliei
46 | Fulica americana
47 | Pachyramphus aglaiae
48 | Buteo lagopus
49 | Cygnus atratus
50 | Philesturnus rufusater
51 | Larus marinus
52 | Pitangus sulphuratus
53 | Anas rubripes
54 | Anthus novaeseelandiae novaeseelandiae
55 | Sayornis phoebe
56 | Sayornis nigricans
57 | Tityra semifasciata
58 | Dryocopus lineatus
59 | Porphyrio melanotus
60 | Anas bahamensis
61 | Egretta novaehollandiae
62 | Anas crecca carolinensis
63 | Alectoris chukar
64 | Tachybaptus dominicus
65 | Artemisiospiza belli
66 | Gallus gallus
67 | Cardinalis sinuatus
68 | Cardinalis cardinalis
69 | Melospiza lincolnii
70 | Podilymbus podiceps
71 | Melospiza georgiana
72 | Meleagris gallopavo
73 | Meleagris ocellata
74 | Lagopus lagopus
75 | Spizella atrogularis
76 | Pyrrhocorax graculus
77 | Spizella breweri
78 | Sialia currucoides
79 | Spizella pusilla
80 | Anas superciliosa
81 | Passerella iliaca
82 | Phoenicopterus ruber
83 | Sylvia atricapilla
84 | Vireo bellii
85 | Vireo plumbeus
86 | Vireo philadelphicus
87 | Vireo flavifrons
88 | Vireo olivaceus
89 | Zonotrichia querula
90 | Vireo huttoni
91 | Zonotrichia albicollis
92 | Zonotrichia atricapilla
93 | Emberiza citrinella
94 | Bucephala islandica
95 | Emberiza schoeniclus
96 | Vireo gilvus
97 | Serinus serinus
98 | Serinus mozambicus
99 | Lophura leucomelanos
100 | Euphonia elegantissima
101 | Euphonia hirundinacea
102 | Euphonia affinis
103 | Agelaius tricolor
104 | Momotus lessonii
105 | Zosterops japonicus
106 | Phalacrocorax pelagicus
107 | Icterus cucullatus
108 | Icterus graduacauda
109 | Motacilla aguimp
110 | Anas superciliosa × platyrhynchos
111 | Icterus pustulatus
112 | Icterus gularis
113 | Carduelis cannabina
114 | Catharus minimus
115 | Amaurornis phoenicurus
116 | Pavo cristatus
117 | Rallus crepitans
118 | Nestor meridionalis septentrionalis
119 | Pipilo chlorurus
120 | Pipilo maculatus
121 | Pipilo erythrophthalmus
122 | Cairina moschata domestica
123 | Phalacrocorax varius
124 | Picoides dorsalis
125 | Picoides nuttallii
126 | Picoides scalaris
127 | Callipepla gambelii
128 | Pyrrhula pyrrhula
129 | Phalacrocorax brasilianus
130 | Picoides pubescens
131 | Colinus virginianus
132 | Sporophila torqueola
133 | Picoides villosus
134 | Calidris pusilla
135 | Picoides arcticus
136 | Aythya marila
137 | Phaethon aethereus
138 | Sturnella magna
139 | Melopsittacus undulatus
140 | Aythya affinis
141 | Aythya novaeseelandiae
142 | Cyrtonyx montezumae
143 | Pelecanus occidentalis
144 | Cinclus cinclus
145 | Chen rossii
146 | Callipepla californica
147 | Quiscalus quiscula
148 | Quiscalus mexicanus
149 | Callipepla squamata
150 | Dryocopus pileatus
151 | Passerina caerulea
152 | Amazilia beryllina
153 | Geothlypis trichas
154 | Trogon melanocephalus
155 | Sylvia communis
156 | Pinicola enucleator
157 | Coccothraustes vespertinus
158 | Coccothraustes coccothraustes
159 | Vermivora chrysoptera
160 | Opisthocomus hoazin
161 | Setophaga coronata coronata
162 | Diglossa baritula
163 | Saltator coerulescens
164 | Saltator atriceps
165 | Sicalis flaveola
166 | Aix galericulata
167 | Junco hyemalis hyemalis
168 | Eupsittula canicularis
169 | Microcarbo melanoleucos
170 | Piranga rubra
171 | Piranga olivacea
172 | Piranga flava
173 | Amphispiza bilineata
174 | Larus dominicanus
175 | Piaya cayana
176 | Aimophila ruficeps
177 | Melanerpes lewis
178 | Melanerpes uropygialis
179 | Passerculus sandwichensis
180 | Melanerpes pucherani
181 | Salpinctes obsoletus
182 | Melanerpes carolinus
183 | Melanerpes chrysogenys
184 | Melanerpes formicivorus
185 | Colaptes auratus
186 | Basileuterus rufifrons
187 | Larus michahellis
188 | Ramphocelus passerinii
189 | Athene cunicularia
190 | Branta hutchinsii
191 | Fringilla montifringilla
192 | Fringilla coelebs
193 | Junco hyemalis
194 | Cuculus canorus
195 | Junco phaeonotus
196 | Ammodramus nelsoni
197 | Ammodramus savannarum
198 | Ammodramus maritimus
199 | Coccyzus erythropthalmus
200 | Coccyzus minor
201 | Coccyzus americanus
202 | Nucifraga columbiana
203 | Crotophaga sulcirostris
204 | Pooecetes gramineus
205 | Arremonops rufivirgatus
206 | Geococcyx californianus
207 | Geococcyx velox
208 | Coereba flaveola
209 | Passerina ciris
210 | Alectura lathami
211 | Passerina leclancherii
212 | Passerina amoena
213 | Icteria virens
214 | Crax rubra
215 | Penelope purpurascens
216 | Copsychus malabaricus
217 | Paroaria capitata
218 | Cyanerpes cyaneus
219 | Microcarbo melanoleucos brevirostris
220 | Sphyrapicus thyroideus
221 | Pheucticus ludovicianus
222 | Sphyrapicus ruber
223 | Pheucticus melanocephalus
224 | Sphyrapicus nuchalis
225 | Ortalis poliocephala
226 | Ortalis vetula
227 | Corvus albus
228 | Mniotilta varia
229 | Volatinia jacarina
230 | Thraupis palmarum
231 | Momotus mexicanus
232 | Euphagus cyanocephalus
233 | Cacatua galerita
234 | Junco hyemalis oreganus
235 | Pluvialis fulva
236 | Molothrus aeneus
237 | Molothrus ater
238 | Merops pusillus
239 | Merops apiaster
240 | Pteroglossus torquatus
241 | Loxia curvirostra
242 | Merops orientalis
243 | Loxia leucoptera
244 | Coracias garrulus
245 | Coracias caudatus
246 | Coracias benghalensis
247 | Xanthocephalus xanthocephalus
248 | Chondestes grammacus
249 | Dolichonyx oryzivorus
250 | Pandion haliaetus
251 | Phainopepla nitens
252 | Tyrannus couchii
253 | Phylloscopus collybita
254 | Circus cyaneus hudsonius
255 | Grallina cyanoleuca
256 | Plectrophenax nivalis
257 | Calamospiza melanocorys
258 | Regulus calendula
259 | Regulus ignicapilla
260 | Regulus regulus
261 | Regulus satrapa
262 | Tyrannus melancholicus
263 | Pelecanus conspicillatus
264 | Aulacorhynchus prasinus
265 | Todiramphus sanctus
266 | Icterus bullockii
267 | Spiza americana
268 | Tyrannus dominicensis
269 | Chlidonias niger
270 | Oriturus superciliosus
271 | Psarocolius montezuma
272 | Turdus pilaris
273 | Notiomystis cincta
274 | Sagittarius serpentarius
275 | Psittacula krameri
276 | Platycercus eximius
277 | Protonotaria citrea
278 | Megaceryle torquata
279 | Nestor meridionalis
280 | Amazona viridigenalis
281 | Amazona albifrons
282 | Amazona oratrix
283 | Saxicola rubetra
284 | Ara militaris
285 | Spizelloides arborea
286 | Ceryle rudis
287 | Chloroceryle aenea
288 | Chloroceryle amazona
289 | Myiozetetes similis
290 | Toxostoma curvirostre
291 | Megaceryle alcyon
292 | Eremophila alpestris
293 | Alisterus scapularis
294 | Cinnyris jugularis
295 | Xiphorhynchus flavigaster
296 | Jacana jacana
297 | Phalaropus fulicarius
298 | Streptopelia turtur
299 | Pica hudsonia
300 | Corvus cornix
301 | Myiopsitta monachus
302 | Streptopelia decaocto
303 | Piranga ludoviciana
304 | Ixobrychus exilis
305 | Auriparus flaviceps
306 | Geothlypis tolmiei
307 | Columba livia
308 | Setophaga citrina
309 | Setophaga cerulea
310 | Columba palumbus
311 | Piranga bidentata
312 | Patagioenas leucocephala
313 | Patagioenas fasciata
314 | Patagioenas flavirostris
315 | Setophaga discolor
316 | Chordeiles minor
317 | Chordeiles acutipennis
318 | Platalea leucorodia
319 | Phalaenoptilus nuttallii
320 | Haemorhous mexicanus
321 | Haemorhous purpureus
322 | Nyctidromus albicollis
323 | Campephilus guatemalensis
324 | Toxostoma rufum
325 | Leptotila verreauxi
326 | Nyctibius jamaicensis
327 | Anas penelope
328 | Buteo plagiatus
329 | Selasphorus calliope
330 | Megascops kennicottii
331 | Porphyrio poliocephalus
332 | Megascops asio
333 | Zenaida auriculata
334 | Hymenolaimus malacorhynchos
335 | Setophaga caerulescens
336 | Camptostoma imberbe
337 | Caracara plancus
338 | Columbina passerina
339 | Eupsittula nana
340 | Nestor notabilis
341 | Columbina talpacoti
342 | Geopelia striata
343 | Athene noctua
344 | Crotophaga ani
345 | Sialia sialis
346 | Platalea alba
347 | Bubo virginianus
348 | Petrochelidon fulva
349 | Progne subis
350 | Setophaga coronata auduboni
351 | Hirundo neoxena
352 | Hirundo rustica
353 | Calidris virgata
354 | Calidris pugnax
355 | Platalea regia
356 | Tachycineta thalassina
357 | Bostrychia hagedash
358 | Riparia riparia
359 | Eudocimus albus
360 | Plegadis falcinellus
361 | Plegadis chihi
362 | Corvus corax
363 | Stelgidopteryx serripennis
364 | Sula dactylatra
365 | Sula sula
366 | Sula leucogaster
367 | Morus serrator
368 | Eudyptula minor
369 | Megadyptes antipodes
370 | Scopus umbretta
371 | Troglodytes troglodytes
372 | Calidris canutus
373 | Lanius collurio
374 | Calidris bairdii
375 | Meleagris gallopavo intermedia
376 | Calidris mauri
377 | Calidris maritima
378 | Calidris alpina
379 | Calidris ferruginea
380 | Calidris melanotos
381 | Limnodromus griseus
382 | Malurus cyaneus
383 | Tringa nebularia
384 | Todiramphus sanctus vagans
385 | Tringa ochropus
386 | Tringa glareola
387 | Tringa melanoleuca
388 | Tringa flavipes
389 | Numenius arquata
390 | Numenius phaeopus
391 | Phalacrocorax carbo novaehollandiae
392 | Petroica macrocephala macrocephala
393 | Petroica australis longipes
394 | Prosthemadera novaeseelandiae novaeseelandiae
395 | Asio flammeus
396 | Rhipidura fuliginosa fuliginosa
397 | Scolopax minor
398 | Arenaria interpres
399 | Arenaria melanocephala
400 | Rhipidura fuliginosa placabilis
401 | Limosa limosa
402 | Limosa haemastica
403 | Limosa fedoa
404 | Phalaropus lobatus
405 | Bartramia longicauda
406 | Limosa lapponica
407 | Aegolius acadicus
408 | Actitis hypoleucos
409 | Trichoglossus haematodus
410 | Surnia ulula
411 | Polioptila caerulea
412 | Spizella passerina
413 | Pycnonotus jocosus
414 | Passerina cyanea
415 | Passerina versicolor
416 | Manorina melanocephala
417 | Ocyphaps lophotes
418 | Jabiru mycteria
419 | Pycnonotus cafer
420 | Anser cygnoides domesticus
421 | Picus viridis
422 | Phoebastria nigripes
423 | Struthio camelus
424 | Phoebastria immutabilis
425 | Fulmarus glacialis
426 | Francolinus pondicerianus
427 | Cynanthus latirostris
428 | Podiceps nigricollis
429 | Podiceps cristatus
430 | Podiceps auritus
431 | Dendrocopos major
432 | Podiceps grisegena
433 | Tachybaptus ruficollis
434 | Charadrius montanus
435 | Phalacrocorax auritus
436 | Phalacrocorax carbo
437 | Phalacrocorax penicillatus
438 | Aechmophorus clarkii
439 | Pelecanus onocrotalus
440 | Pelecanus erythrorhynchos
441 | Zenaida macroura
442 | Vanellus miles
443 | Larus occidentalis
444 | Trogon massena
445 | Larus thayeri
446 | Larus heermanni
447 | Larus livens
448 | Larus canus
449 | Larus glaucoides
450 | Larus delawarensis
451 | Trogon collaris
452 | Zenaida asiatica
453 | Larus fuscus
454 | Larus californicus
455 | Prosthemadera novaeseelandiae
456 | Trogon elegans
457 | Larus glaucescens
458 | Trogon citreolus
459 | Cepphus columba
460 | Himantopus leucocephalus
461 | Cepphus grylle
462 | Anthornis melanura
463 | Leptoptilos crumenifer
464 | Threskiornis moluccus
465 | Thraupis episcopus
466 | Geranoaetus albicaudatus
467 | Sterna paradisaea
468 | Sterna hirundo
469 | Sterna forsteri
470 | Lanius excubitor
471 | Pharomachrus mocinno
472 | Sterna striata
473 | Stercorarius parasiticus
474 | Stercorarius pomarinus
475 | Anas gracilis
476 | Rissa tridactyla
477 | Rynchops niger
478 | Alca torda
479 | Fratercula arctica
480 | Fratercula cirrhata
481 | Turdus merula
482 | Turdus plumbeus
483 | Turdus grayi
484 | Turdus migratorius
485 | Turdus viscivorus
486 | Cerorhinca monocerata
487 | Turdus philomelos
488 | Galbula ruficauda
489 | Jacana spinosa
490 | Saxicola rubicola
491 | Upupa epops
492 | Euphagus carolinus
493 | Gavia pacifica
494 | Mimus gilvus
495 | Passer italiae
496 | Gavia immer
497 | Gavia stellata
498 | Oenanthe oenanthe
499 | Fregata magnificens
500 | Fregata minor
501 | Falco subbuteo
502 | Falco mexicanus
503 | Falco femoralis
504 | Falco peregrinus
505 | Falco rufigularis
506 | Falco sparverius
507 | Strix varia
508 | Falco columbarius
509 | Gallinula chloropus
510 | Cardellina pusilla
511 | Catharus ustulatus
512 | Falco novaeseelandiae
513 | Catharus guttatus
514 | Catharus fuscescens
515 | Caracara cheriway
516 | Herpetotheres cachinnans
517 | Calcarius lapponicus
518 | Milvago chimachima
519 | Ciconia ciconia
520 | Mycteria americana
521 | Mycteria ibis
522 | Sialia mexicana
523 | Ephippiorhynchus senegalensis
524 | Cathartes aura
525 | Myadestes townsendi
526 | Cathartes burrovianus
527 | Sarcoramphus papa
528 | Coragyps atratus
529 | Strix nebulosa
530 | Anastomus lamelligerus
531 | Pluvialis squatarola
532 | Gymnogyps californianus
533 | Muscicapa striata
534 | Charadrius vociferus
535 | Charadrius wilsonia
536 | Charadrius melodus
537 | Phoenicurus phoenicurus
538 | Phoenicurus ochruros
539 | Charadrius dubius
540 | Eumomota superciliosa
541 | Anas querquedula
542 | Himantopus mexicanus
543 | Haematopus bachmani
544 | Pica pica
545 | Haematopus ostralegus
546 | Haematopus unicolor
547 | Vanellus vanellus
548 | Vanellus spinosus
549 | Vanellus armatus
550 | Luscinia svecica
551 | Columbina inca
552 | Recurvirostra avosetta
553 | Phasianus colchicus
554 | Pluvialis dominica
555 | Cinclus mexicanus
556 | Erithacus rubecula
557 | Melanerpes aurifrons
558 | Charadrius hiaticula
559 | Egretta gularis
560 | Egretta caerulea
561 | Egretta tricolor
562 | Egretta thula
563 | Egretta garzetta
564 | Egretta sacra
565 | Monticola solitarius
566 | Ardea cocoi
567 | Ardea cinerea
568 | Ardea herodias
569 | Nycticorax nycticorax
570 | Turdus rufopalliatus
571 | Ardeola ralloides
572 | Nyctanassa violacea
573 | Aramides cajaneus
574 | Bubulcus ibis
575 | Butorides virescens
576 | Porphyrio martinicus
577 | Botaurus lentiginosus
578 | Cochlearius cochlearius
579 | Anhinga novaehollandiae
580 | Anhinga rufa
581 | Melozone fusca
582 | Aquila chrysaetos
583 | Hylocichla mustelina
584 | Aphelocoma wollweberi
585 | Accipiter striatus
586 | Accipiter nisus
587 | Accipiter gentilis
588 | Egretta rufescens
589 | Bucephala clangula
590 | Anous stolidus
591 | Actitis macularius
592 | Ardea purpurea
593 | Todiramphus chloris
594 | Grus americana
595 | Himantopus himantopus
596 | Glaucidium gnoma
597 | Circus approximans
598 | Circus aeruginosus
599 | Phalacrocorax sulcirostris
600 | Buteo albonotatus
601 | Butorides striata
602 | Platalea ajaja
603 | Buteo brachyurus
604 | Ardea alba
605 | Buteo swainsoni
606 | Alectoris rufa
607 | Buteo lineatus
608 | Buteo jamaicensis
609 | Charadrius nivosus
610 | Tringa incana
611 | Tringa semipalmata
612 | Terathopius ecaudatus
613 | Gallinago delicata
614 | Buteogallus anthracinus
615 | Chroicocephalus philadelphia
616 | Circaetus gallicus
617 | Chroicocephalus novaehollandiae
618 | Chroicocephalus ridibundus
619 | Leucophaeus atricilla
620 | Leucophaeus pipixcan
621 | Onychoprion fuscatus
622 | Sternula antillarum
623 | Hydroprogne caspia
624 | Thalasseus maximus
625 | Thalasseus bergii
626 | Elanus leucurus
627 | Alopochen aegyptiaca
628 | Streptopelia senegalensis
629 | Gerygone igata
630 | Haliaeetus leucocephalus
631 | Cistothorus platensis
632 | Haliaeetus vocifer
633 | Bubo scandiacus
634 | Ciccaba virgata
635 | Bonasa umbellus
636 | Busarellus nigricollis
637 | Rostrhamus sociabilis
638 | Milvus milvus
639 | Gyps fulvus
640 | Ficedula hypoleuca
641 | Momotus coeruliceps
642 | Charadrius semipalmatus
643 | Haliastur indus
644 | Gyps africanus
645 | Ictinia mississippiensis
646 | Dives dives
647 | Baeolophus atricristatus
648 | Baeolophus bicolor
649 | Baeolophus inornatus
650 | Melospiza melodia
651 | Spinus spinus
652 | Motacilla alba
653 | Certhia americana
654 | Bucorvus leadbeateri
655 | Anthus pratensis
656 | Anthus rubescens
657 | Tachycineta albilinea
658 | Poecile carolinensis
659 | Poecile atricapillus
660 | Poecile gambeli
661 | Poecile rufescens
662 | Periparus ater
663 | Chlorophanes spiza
664 | Estrilda astrild
665 | Cyanistes caeruleus
666 | Sphyrapicus varius
667 | Petrochelidon pyrrhonota
668 | Troglodytes pacificus
669 | Troglodytes hiemalis
670 | Passer montanus
671 | Passer domesticus
672 | Aphelocoma californica
673 | Amazilia yucatanensis
674 | Amazilia tzacatl
675 | Dicrurus adsimilis
676 | Amazilia violiceps
677 | Lonchura punctulata
678 | Tigrisoma mexicanum
679 | Porphyrio melanotus melanotus
680 | Melanitta americana
681 | Spizella pallida
682 | Amazilia rutila
683 | Zenaida aurita
684 | Prunella modularis
685 | Falco tinnunculus
686 | Ixoreus naevius
687 | Archilochus colubris
688 | Lampornis clemenciae
689 | Myiarchus tuberculifer
690 | Setophaga ruticilla
691 | Myiarchus tyrannulus
692 | Zosterops lateralis
693 | Zonotrichia leucophrys
694 | Agelaius phoeniceus
695 | Parus major
696 | Zonotrichia capensis
697 | Oreothlypis peregrina
698 | Oreothlypis celata
699 | Oreothlypis ruficapilla
700 | Geothlypis philadelphia
701 | Geothlypis formosa
702 | Setophaga tigrina
703 | Setophaga americana
704 | Setophaga magnolia
705 | Setophaga castanea
706 | Setophaga fusca
707 | Setophaga petechia
708 | Setophaga striata
709 | Setophaga palmarum
710 | Setophaga pinus
711 | Setophaga coronata
712 | Setophaga dominica
713 | Campylopterus hemileucurus
714 | Vireo cassinii
715 | Setophaga nigrescens
716 | Setophaga townsendi
717 | Setophaga occidentalis
718 | Setophaga chrysoparia
719 | Setophaga virens
720 | Cardellina canadensis
721 | Cardellina rubra
722 | Aphelocoma coerulescens
723 | Melanerpes erythrocephalus
724 | Emberiza calandra
725 | Acanthis flammea
726 | Spinus pinus
727 | Thraupis abbas
728 | Spinus psaltria
729 | Spinus lawrencei
730 | Spinus tristis
731 | Threskiornis aethiopicus
732 | Gygis alba
733 | Tachycineta bicolor
734 | Larus dominicanus dominicanus
735 | Lonchura oryzivora
736 | Haematopus palliatus
737 | Chloris chloris
738 | Accipiter cooperii
739 | Vireo solitarius
740 | Selasphorus platycercus
741 | Chroicocephalus scopulinus
742 | Aechmophorus occidentalis
743 | Hemiphaga novaeseelandiae
744 | Xema sabini
745 | Ramphastos sulfuratus
746 | Dacelo novaeguineae
747 | Fulica atra
748 | Hirundo rustica erythrogaster
749 | Calypte costae
750 | Calypte anna
751 | Colaptes auratus cafer
752 | Sula nebouxii
753 | Copsychus saularis
754 | Selasphorus sasin
755 | Selasphorus rufus
756 | Calothorax lucifer
757 | Pycnonotus barbatus
758 | Larus glaucescens × occidentalis
759 | Aphelocoma woodhouseii
760 | Florisuga mellivora
761 | Haematopus finschi
762 | Falcipennis canadensis
763 | Archilochus alexandri
764 | Circus cyaneus
765 | Ardea alba modesta
766 | Myiarchus crinitus
767 | Buteo regalis
768 | Aeronautes saxatalis
769 | Chaetura vauxi
770 | Chaetura pelagica
771 | Setophaga pensylvanica
772 | Lanius ludovicianus
773 | Anhinga anhinga
774 | Acridotheres tristis
775 | Sitta pygmaea
776 | Actophilornis africanus
777 | Sitta canadensis
778 | Sitta europaea
779 | Sitta pusilla
780 | Apus apus
781 | Sturnus vulgaris
782 | Seiurus aurocapilla
783 | Motacilla flava
784 | Vireo griseus
785 | Toxostoma longirostre
786 | Calidris alba
787 | Toxostoma redivivum
788 | Gallinula galeata
789 | Calidris himantopus
790 | Eugenes fulgens
791 | Icterus wagleri
792 | Icterus parisorum
793 | Buteo platypterus
794 | Gallinago gallinago
795 | Icterus spurius
796 | Calidris minutilla
797 | Dumetella carolinensis
798 | Porphyrio hochstetteri
799 | Calidris fuscicollis
800 | Phalaropus tricolor
801 | Colaptes auratus auratus
802 | Melanotis caerulescens
803 | Tiaris olivaceus
804 | Oreoscoptes montanus
805 | Limnodromus scolopaceus
806 | Tringa solitaria
807 | Sitta carolinensis
808 | Tringa totanus
809 | Dendrocygna autumnalis
810 | Dendrocygna viduata
811 | Dendrocygna bicolor
812 | Icterus abeillei
813 | Vanellus chilensis
814 | Cygnus buccinator
815 | Cygnus cygnus
816 | Cygnus columbianus
817 | Cygnus olor
818 | Icterus galbula
819 | Anas platyrhynchos
820 | Anas acuta
821 | Anas crecca
822 | Anas cyanoptera
823 | Anas fulvigula
824 | Anas discors
825 | Anas strepera
826 | Anas clypeata
827 | Anas chlorotis
828 | Rhipidura leucophrys
829 | Anas americana
830 | Bucephala albeola
831 | Mergus serrator
832 | Mergus merganser
833 | Anser anser
834 | Anser albifrons
835 | Somateria mollissima
836 | Rallus obsoletus
837 | Platycercus elegans
838 | Melanitta fusca
839 | Milvus migrans
840 | Gelochelidon nilotica
841 | Ninox novaeseelandiae novaeseelandiae
842 | Melanitta perspicillata
843 | Aythya collaris
844 | Aythya ferina
845 | Aythya fuligula
846 | Numenius americanus
847 | Chen caerulescens
848 | Chamaea fasciata
849 | Branta canadensis
850 | Thalasseus elegans
851 | Branta sandvicensis
852 | Aythya americana
853 | Aix sponsa
854 | Lophodytes cucullatus
855 | Histrionicus histrionicus
856 | Aratinga nenday
857 | Psittacara holochlorus
858 | Cairina moschata
859 | Netta rufina
860 | Psittacara erythrogenys
861 | Sayornis saya
862 | Aythya valisineria
863 | Picoides albolarvatus
864 | Vermivora cyanoptera
865 | Corvus caurinus
866 | Asio otus
867 | Corvus brachyrhynchos
868 | Clangula hyemalis
869 | Chenonetta jubata
870 | Thalasseus sandvicensis
871 | Eolophus roseicapilla
872 | Colaptes rubiginosus
873 | Meleagris gallopavo silvestris
874 | Ptiliogonys cinereus
875 | Elanoides forficatus
876 | Carduelis carduelis
877 | Cassiculus melanicterus
878 | Dendragapus fuliginosus
879 | Psaltriparus minimus
880 | Aegithalos caudatus
881 | Zosterops lateralis lateralis
882 | Haliaeetus leucogaster
883 | Uria aalge
884 | Tringa semipalmata inornatus
885 | Alauda arvensis
886 | Galerida cristata
887 | Delichon urbicum
888 | Helmitheros vermivorum
889 | Hylocharis leucotis
890 | Mimus polyglottos
891 | Gymnorhina tibicen
892 | Alcedo atthis
893 | Streptopelia chinensis
894 | Bombycilla cedrorum
895 | Bombycilla garrulus
896 | Tadorna tadorna
897 | Petroica australis australis
898 | Amazona autumnalis
899 | Dendragapus obscurus
900 | Catherpes mexicanus
901 | Tadorna ferruginea
902 | Campylorhynchus brunneicapillus
903 | Campylorhynchus rufinucha
904 | Rhipidura fuliginosa
905 | Polioptila melanura
906 | Pelecanus occidentalis carolinensis
907 | Melozone aberti
908 | Melozone crissalis
909 | Thryothorus ludovicianus
910 | Parabuteo unicinctus
911 | Anas platyrhynchos domesticus
912 | Troglodytes aedon
913 | Buteo lineatus elegans
914 | Thamnophilus doliatus
915 | Thryomanes bewickii
916 | Tadorna variegata
917 | Myioborus miniatus
918 | Phalacrocorax varius varius
919 | Myioborus pictus
920 | Larus argentatus smithsonianus
921 | Parkesia motacilla
922 | Sula granti
923 | Ara macao
924 | Peucaea ruficauda
925 | Calidris subruficollis
926 | Phoenicopterus roseus
927 | Morus bassanus
928 | Pelecanus occidentalis californicus
929 | Glaucidium brasilianum
930 | Oxyura jamaicensis
931 | Myiarchus cinerascens
932 | Chloroceryle americana
933 | Sturnella neglecta
934 | Ramphastos ambiguus
935 | Paroaria coronata
936 | Buteo buteo
937 | Myiodynastes luteiventris
938 | Contopus sordidulus
939 | Corvus corone
940 | Cyanoramphus novaezelandiae
941 | Contopus virens
942 | Contopus pertinax
943 | Contopus cooperi
944 | Larus argentatus
945 | Halcyon smyrnensis
946 | Onychognathus morio
947 | Cyanocompsa parellina
948 | Cistothorus palustris
949 | Tyto alba
950 | Trogon caligatus
951 | Corvus monedula
952 | Corvus ossifragus
953 | Spheniscus demersus
954 | Corvus frugilegus
955 | Corvus splendens
956 | Branta bernicla
957 | Larus hyperboreus
958 | Columba livia domestica
959 | Garrulus glandarius
960 | Anser anser domesticus
961 | Mitrephanes phaeocercus
962 | Ardenna creatopus
963 | Ardenna gravis

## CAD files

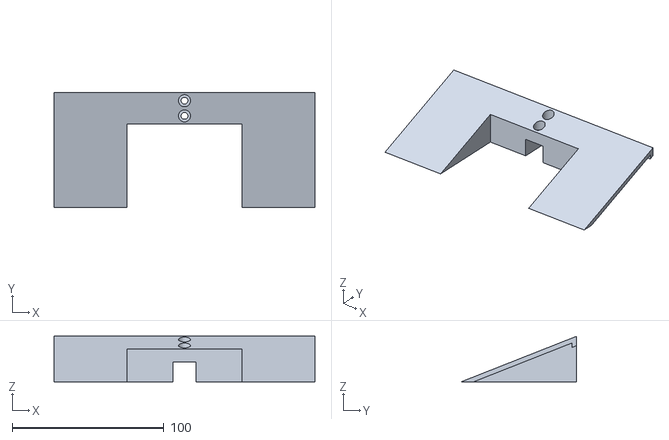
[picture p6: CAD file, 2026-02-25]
mechanic/weight_main.stl
172.0 x 76.0 x 30.0

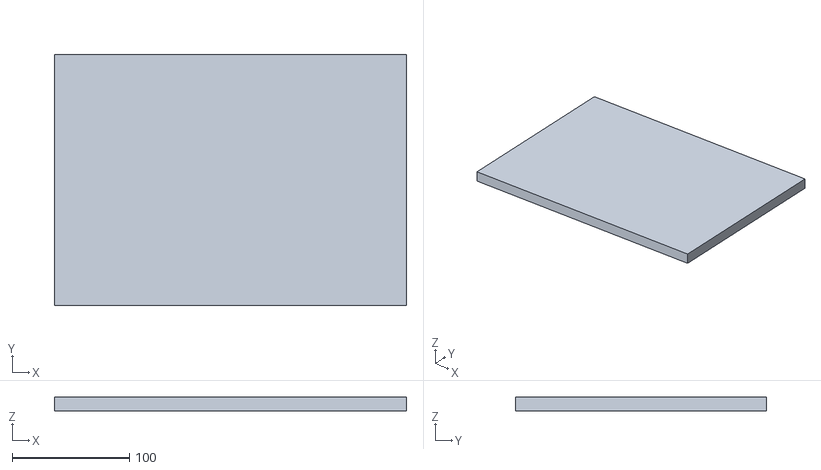
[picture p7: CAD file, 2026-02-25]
mechanic/mill/roof.stl
300.0 x 214.0 x 12.0

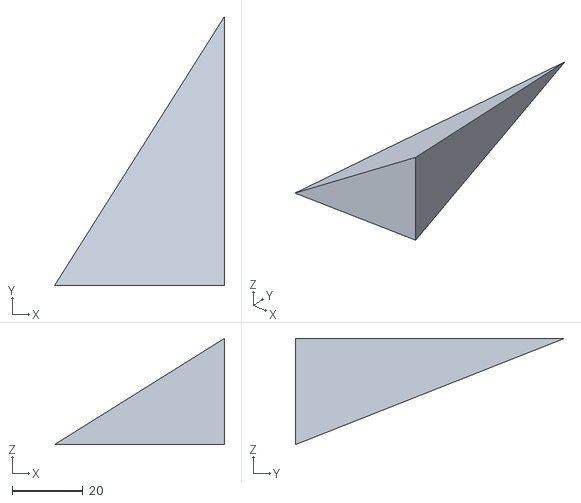
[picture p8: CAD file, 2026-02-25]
mechanic/weight_right.stl
48.0 x 76.0 x 30.0

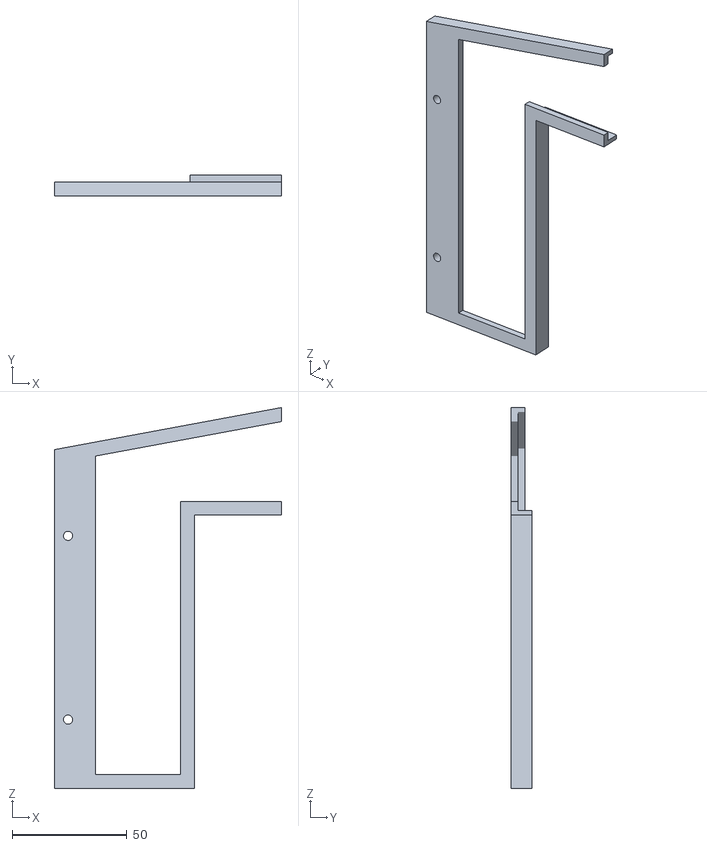
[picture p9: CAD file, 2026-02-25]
mechanic/frame_left.stl
99.0 x 9.00 x 165.9

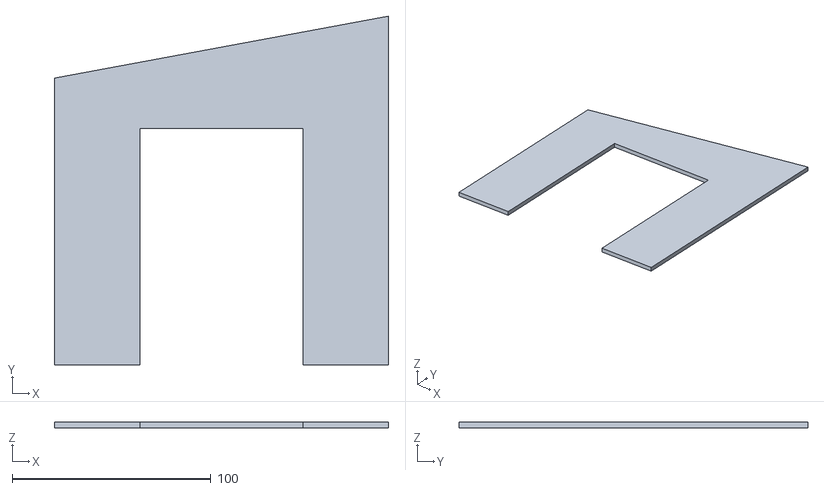
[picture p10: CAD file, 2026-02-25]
mechanic/mill/window.stl
168.0 x 175.4 x 3.00

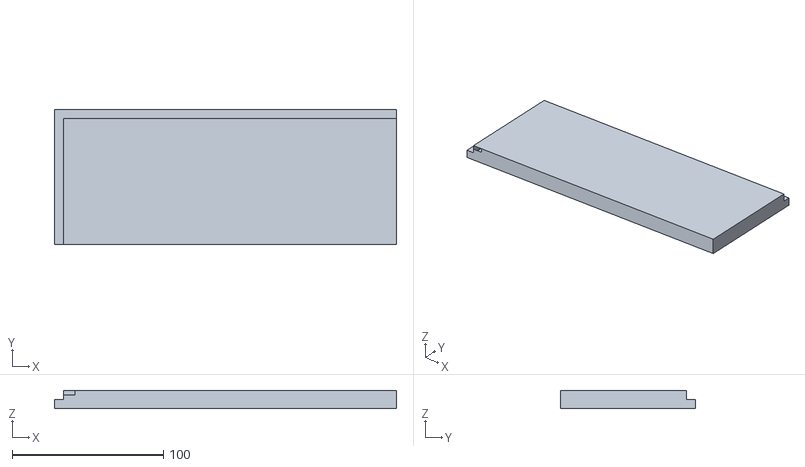
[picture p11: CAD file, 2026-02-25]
mechanic/mill/right.stl
226.0 x 89.0 x 12.0

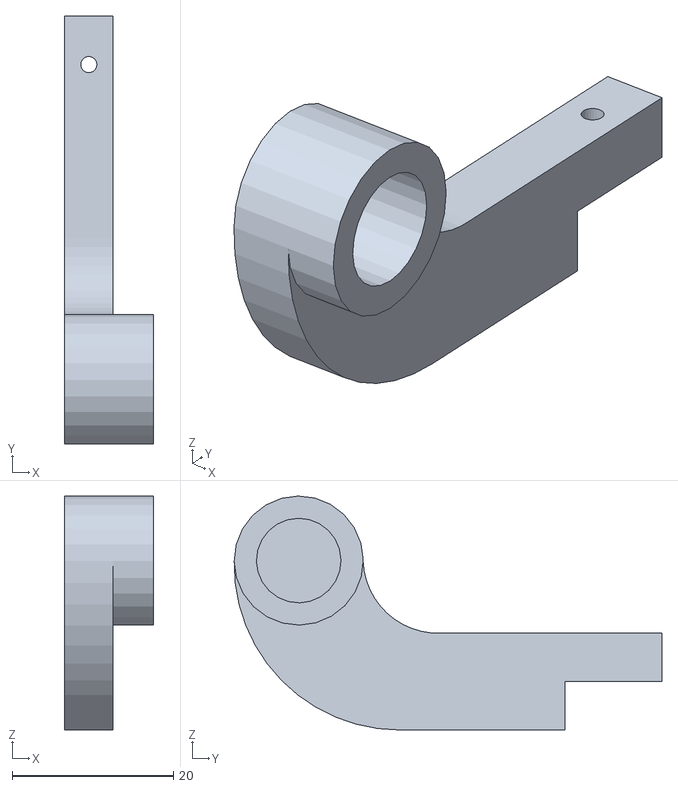
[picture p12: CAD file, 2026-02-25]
mechanic/bar_right.stl
11.0 x 53.0 x 29.0

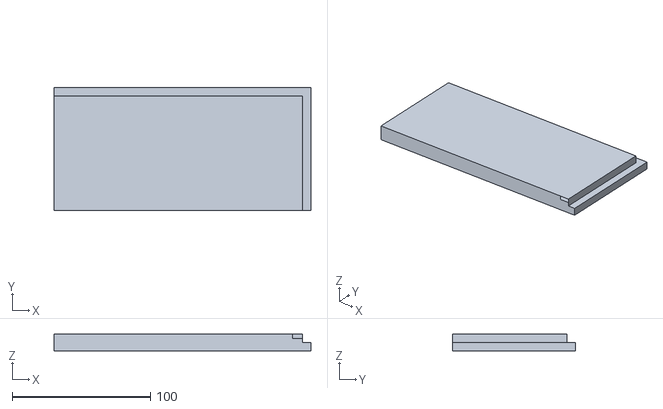
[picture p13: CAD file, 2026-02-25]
mechanic/mill/left.stl
186.0 x 89.0 x 12.0

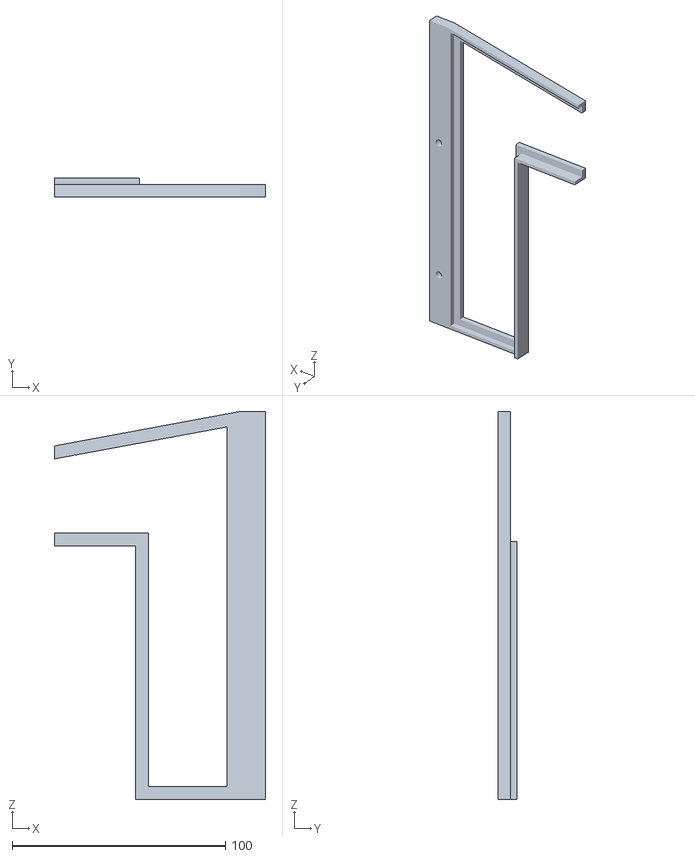
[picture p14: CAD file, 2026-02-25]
mechanic/frame_right.stl
99.0 x 9.00 x 182.0

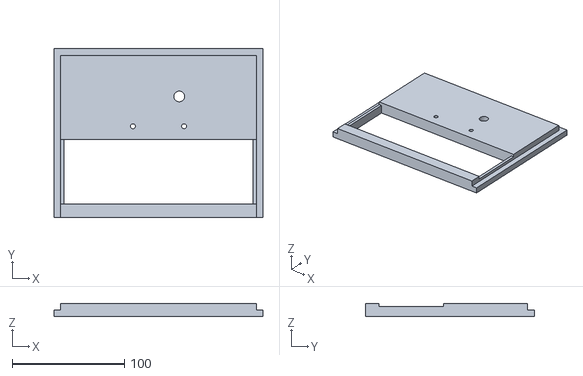
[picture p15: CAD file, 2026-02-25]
mechanic/mill/base.stl
186.0 x 150.0 x 12.0

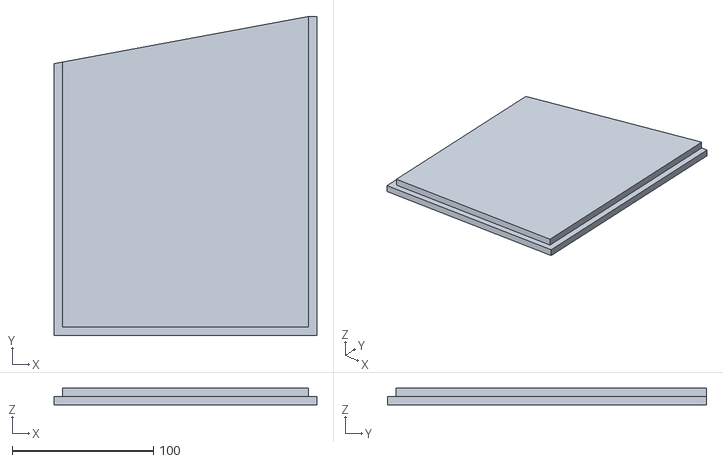
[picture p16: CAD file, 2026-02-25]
mechanic/mill/back.stl
186.0 x 226.0 x 12.0

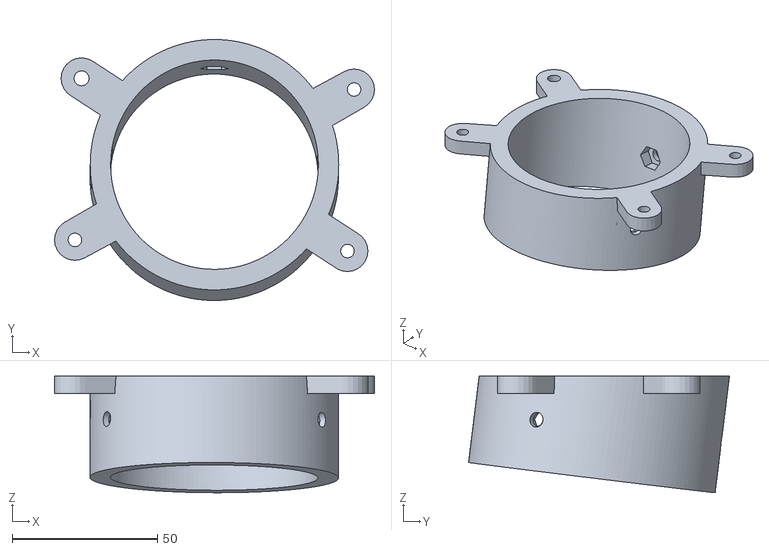
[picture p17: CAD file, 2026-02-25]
mechanic/pole_mount.stl
110.3 x 89.9 x 40.1

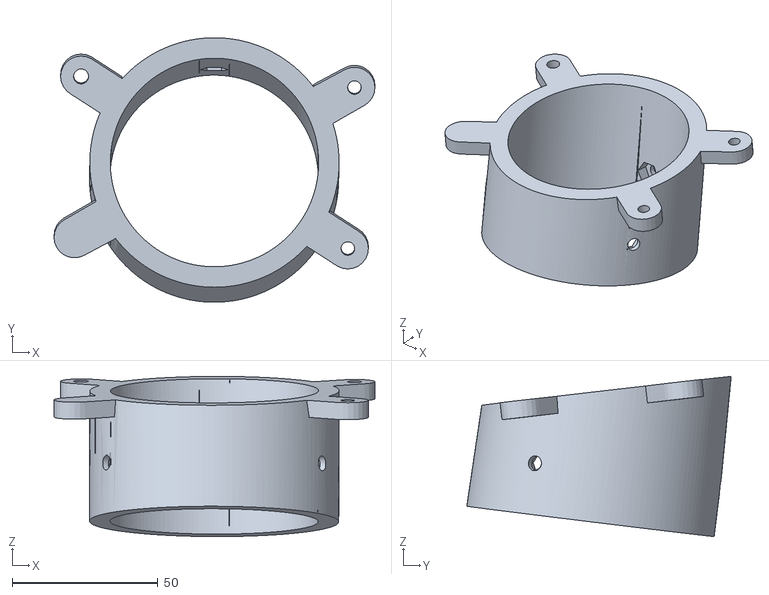
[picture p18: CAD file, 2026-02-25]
mechanic/pole_mount_2.STL
110.3 x 90.9 x 55.0

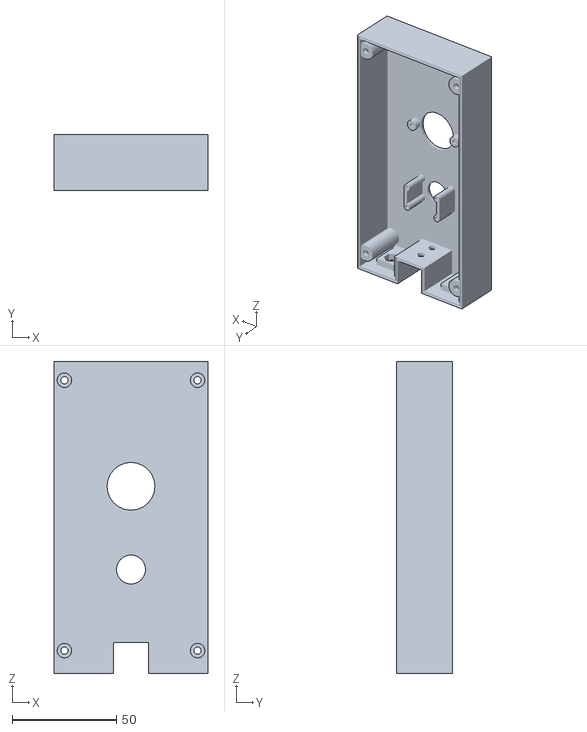
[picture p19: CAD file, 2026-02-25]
mechanic/box_top.stl
74.0 x 27.0 x 150.0

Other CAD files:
mechanic/bar_left.stl
mechanic/box_bottom.stl
mechanic/weight_left.stl
mechanic/feeder_plate.stl
mechanic/konstruktion.skp

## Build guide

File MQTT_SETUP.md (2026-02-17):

# Home Assistant MQTT Integration - Setup Anleitung

## Übersicht

Birdy publiziert alle 60 Sekunden Sensor-Daten via MQTT zu Home Assistant:
- **Futtermenge** (Gewicht in Gramm)
- **Vogel anwesend** (Binary Sensor)
- **Letzte Spezies** (Name des Vogels)
- **Besuche heute** (Anzahl Detections)

## 1. MQTT Broker in Home Assistant einrichten

### Mosquitto Broker installieren
1. **Home Assistant** öffnen
2. **Einstellungen** → **Add-ons** → **Add-on Store**
3. Suche nach **"Mosquitto broker"**
4. **Installieren** klicken
5. **Start** klicken
6. **Start on boot** aktivieren

### MQTT User anlegen
1. Öffne das **Mosquitto broker Add-on**
2. Gehe zum Tab **"Konfiguration"**
3. Füge einen User hinzu (oder nutze die Home Assistant User-Verwaltung):

```yaml
logins:
  - username: birdy
    password: birdy123
```

4. **Speichern** und **Neustart** des Add-ons

## 2. MQTT Integration in Home Assistant aktivieren

1. **Einstellungen** → **Geräte & Dienste** → **Integration hinzufügen**
2. Suche nach **"MQTT"**
3. Konfiguriere:
   - **Broker**: `localhost` (wenn auf demselben System) oder IP-Adresse
   - **Port**: `1883`
   - **Username**: `birdy`
   - **Password**: `birdy123`
4. **Absenden** klicken

## 3. Birdy MQTT Konfiguration

Bearbeite `/home/pi/birdy_project/birdy_config/settings.py`:

```python
BIRDY_SETTINGS = {
    ...
    # MQTT Home Assistant Integration
    'MQTT_BROKER': 'localhost',     # IP von Home Assistant (z.B. '192.168.1.100')
    'MQTT_PORT': 1883,
    'MQTT_USERNAME': 'birdy',       # Mosquitto User
    'MQTT_PASSWORD': 'birdy123',    # Mosquitto Passwort
    'MQTT_TOPIC_PREFIX': 'birdy',
}
```

**Wichtig:**
- Wenn Home Assistant auf **demselben Raspberry Pi** läuft: `'MQTT_BROKER': 'localhost'`
- Wenn Home Assistant auf **anderem System** läuft: `'MQTT_BROKER': '192.168.1.100'` (IP-Adresse)

## 4. System neu starten

```bash
cd /home/pi/birdy_project
./restart_birdy.sh
```

## 5. Testen der Verbindung

### In Home Assistant
Nach dem Neustart sollten automatisch **neue Geräte und Sensoren** erscheinen:

1. **Einstellungen** → **Geräte & Dienste** → **MQTT**
2. Du solltest das Gerät **"Birdy Bird Feeder"** sehen mit folgenden Entities:
   - `sensor.birdy_feed_weight` (Futtermenge in g)
   - `binary_sensor.birdy_bird_present` (Vogel anwesend)
   - `sensor.birdy_last_species` (Letzte Vogelart)
   - `sensor.birdy_visits_today` (Besuche heute)

### MQTT Logs prüfen

**In Birdy Logs:**
```bash
tail -f /home/pi/birdy_project/logs/birdy.log | grep MQTT
```

Du solltest sehen:
```
INFO MQTT client connecting to localhost:1883
INFO MQTT connected successfully
INFO Home Assistant discovery messages published
```

**In Celery Worker Logs:**
```bash
tail -f /home/pi/birdy_project/logs/celery_worker.log | grep mqtt
```

Alle 60 Sekunden sollte Status publiziert werden.

## 6. Troubleshooting

### MQTT verbindet nicht
```bash
# Prüfe ob Mosquitto läuft
mosquitto -h

# Teste Verbindung manuell
mosquitto_sub -h localhost -p 1883 -u birdy -P birdy123 -t 'birdy/#' -v
```

### Birdy publiziert nicht
```bash
# Prüfe Celery Worker Logs
tail -f logs/celery_worker.log

# Prüfe ob publish_status_task läuft
grep "publish_status_task" logs/celery_worker.log
```

### Home Assistant erkennt Gerät nicht
1. Gehe zu **MQTT Integration** in Home Assistant
2. Klicke auf **"Geräte neu erkennen"** oder **"MQTT neu laden"**
3. Prüfe MQTT Explorer (optional):
   - Topic: `homeassistant/sensor/birdy/#`
   - Topic: `birdy/#`

## 7. Was wird publiziert?

### Discovery Messages (einmalig bei Verbindung)
```
homeassistant/sensor/birdy/feed_weight/config
homeassistant/binary_sensor/birdy/bird_detected/config
homeassistant/sensor/birdy/species/config
homeassistant/sensor/birdy/visits_today/config
```

### Status Updates (alle 60 Sekunden)
```
birdy/feed/weight → "125.5"
birdy/stats/today → "7"
birdy/stats/daily → {"date": "2026-01-20", "total_visits": 7, "top_species": [...]}
```

### Bei Vogel-Detektion (Event-basiert)
```
birdy/bird/detected → "ON"
birdy/bird/species → "Blaumeise"
birdy/bird/attributes → {"species": "Blaumeise", "confidence": "85%", ...}
```

## 8. Home Assistant Dashboard Beispiel

```yaml
type: entities
title: Birdy Vogelfutterhaus
entities:
  - entity: sensor.birdy_feed_weight
    name: Futtermenge
  - entity: binary_sensor.birdy_bird_present
    name: Vogel anwesend
  - entity: sensor.birdy_last_species
    name: Letzte Art
  - entity: sensor.birdy_visits_today
    name: Besuche heute
```

## Architektur

```
┌─────────────────────┐
│   start_birdy       │
│   (Main Process)    │
│   - Updates DB      │
└─────────────────────┘
           │
           ▼
    ┌──────────────┐
    │  DATABASE    │
    │ SensorStatus │
    └──────────────┘
           │
           ▼
┌─────────────────────┐
│  Celery Worker      │ (alle 60s)
│  publish_status     │──────┐
└─────────────────────┘      │
                             │
                             ▼
                     ┌──────────────┐
                     │ MQTT Broker  │
                     │  Mosquitto   │
                     └──────────────┘
                             │
                             ▼
                    ┌─────────────────┐
                    │ Home Assistant  │
                    │   Integration   │
                    └─────────────────┘
```

## Fertig!

Nach dem Setup solltest du alle Birdy-Sensoren in Home Assistant sehen und verwenden können.

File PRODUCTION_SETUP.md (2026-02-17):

# Birdy Production Setup Guide

Vollständige Anleitung für die Produktiv-Installation von Birdy auf Raspberry Pi.

## Übersicht

Für den Produktiv-Betrieb werden folgende Komponenten als Systemd-Services eingerichtet:

1. **Redis** - Message Broker (bereits als System-Service)
2. **Celery Worker** - Background Tasks (Sensor Updates, MQTT, Statistiken)
3. **Celery Beat** - Periodische Tasks (MQTT Publishing, Backup)
4. **Gunicorn** - Django WSGI Server (Production Web Server)
5. **Birdy Detection** - Bird Detection System (PIR + Kamera + ML)
6. **Nginx** - Reverse Proxy & Static Files (optional, empfohlen)

---

## 1. Voraussetzungen

```bash
# System-Pakete installieren
sudo apt-get update
sudo apt-get install -y nginx redis-server postgresql postgresql-contrib

# Gunicorn installieren (im venv)
source ~/birdy_project/venv/bin/activate
pip install gunicorn
```

---

## 2. Datenbank (Production)

### Option A: SQLite (aktuell, einfach)
- Funktioniert für kleine bis mittlere Installationen
- Aktuell in Verwendung: `db.sqlite3`
- **Kein Setup nötig**

### Option B: PostgreSQL (empfohlen für Production)

```bash
# PostgreSQL Datenbank erstellen
sudo -u postgres psql

CREATE DATABASE birdy_db;
CREATE USER birdy_user WITH PASSWORD 'dein_sicheres_passwort';
ALTER ROLE birdy_user SET client_encoding TO 'utf8';
ALTER ROLE birdy_user SET default_transaction_isolation TO 'read committed';
ALTER ROLE birdy_user SET timezone TO 'Europe/Berlin';
GRANT ALL PRIVILEGES ON DATABASE birdy_db TO birdy_user;
\q
```

**Django Settings anpassen** (`birdy_config/settings.py`):

```python
# PostgreSQL installieren
pip install psycopg2-binary

# In settings.py ändern:
DATABASES = {
    'default': {
        'ENGINE': 'django.db.backends.postgresql',
        'NAME': 'birdy_db',
        'USER': 'birdy_user',
        'PASSWORD': 'dein_sicheres_passwort',
        'HOST': 'localhost',
        'PORT': '5432',
    }
}
```

**Migration durchführen:**

```bash
python manage.py migrate
python manage.py createsuperuser
python manage.py collectstatic --noinput
```

---

## 3. Django Production Settings

**Datei erstellen:** `birdy_config/settings_production.py`

```python
from .settings import *

DEBUG = False

ALLOWED_HOSTS = [
    'localhost',
    '127.0.0.1',
    'your-raspberry-pi-ip',  # z.B. 192.168.1.100
    'your-domain.com',       # Falls du eine Domain hast
]

# Static Files
STATIC_ROOT = '/home/pi/birdy_project/staticfiles/'

# Security Settings
CSRF_COOKIE_SECURE = False  # True wenn HTTPS
SESSION_COOKIE_SECURE = False  # True wenn HTTPS
SECURE_SSL_REDIRECT = False  # True wenn HTTPS

# Logging
LOGGING = {
    'version': 1,
    'disable_existing_loggers': False,
    'handlers': {
        'file': {
            'level': 'INFO',
            'class': 'logging.FileHandler',
            'filename': '/home/pi/birdy_project/logs/django.log',
        },
    },
    'loggers': {
        'django': {
            'handlers': ['file'],
            'level': 'INFO',
            'propagate': True,
        },
    },
}
```

**Static Files sammeln:**

```bash
python manage.py collectstatic --noinput
```

---

## 4. Systemd Service Files

### 4.1 Celery Worker Service

**Datei:** `/etc/systemd/system/birdy-celery-worker.service`

```ini
[Unit]
Description=Birdy Celery Worker (Background Tasks)
After=network.target redis.service

[Service]
Type=forking
User=pi
Group=pi
WorkingDirectory=/home/pi/birdy_project
Environment="PATH=/home/pi/birdy_project/venv/bin"
ExecStart=/home/pi/birdy_project/venv/bin/celery -A birdy_config worker -Q default -l info --logfile=/home/pi/birdy_project/logs/celery_worker.log --detach --pidfile=/tmp/celery_worker.pid
ExecStop=/bin/kill -TERM $MAINPID
PIDFile=/tmp/celery_worker.pid
Restart=always
RestartSec=10

[Install]
WantedBy=multi-user.target
```

### 4.2 Celery Beat Service

**Datei:** `/etc/systemd/system/birdy-celery-beat.service`

```ini
[Unit]
Description=Birdy Celery Beat (Periodic Tasks)
After=network.target redis.service

[Service]
Type=forking
User=pi
Group=pi
WorkingDirectory=/home/pi/birdy_project
Environment="PATH=/home/pi/birdy_project/venv/bin"
ExecStart=/home/pi/birdy_project/venv/bin/celery -A birdy_config beat -l info --logfile=/home/pi/birdy_project/logs/celery_beat.log --detach --pidfile=/tmp/celery_beat.pid
ExecStop=/bin/kill -TERM $MAINPID
PIDFile=/tmp/celery_beat.pid
Restart=always
RestartSec=10

[Install]
WantedBy=multi-user.target
```

### 4.3 Gunicorn Service (Django)

**Datei:** `/etc/systemd/system/birdy-gunicorn.service`

```ini
[Unit]
Description=Birdy Gunicorn (Django WSGI)
After=network.target

[Service]
Type=notify
User=pi
Group=pi
WorkingDirectory=/home/pi/birdy_project
Environment="PATH=/home/pi/birdy_project/venv/bin"
Environment="DJANGO_SETTINGS_MODULE=birdy_config.settings_production"
ExecStart=/home/pi/birdy_project/venv/bin/gunicorn \
    --workers 2 \
    --bind 127.0.0.1:8000 \
    --timeout 120 \
    --access-logfile /home/pi/birdy_project/logs/gunicorn_access.log \
    --error-logfile /home/pi/birdy_project/logs/gunicorn_error.log \
    birdy_config.wsgi:application
ExecReload=/bin/kill -s HUP $MAINPID
KillMode=mixed
TimeoutStopSec=5
PrivateTmp=true
Restart=always
RestartSec=10

[Install]
WantedBy=multi-user.target
```

### 4.4 Birdy Detection Service

**Datei:** `/etc/systemd/system/birdy-detection.service`

```ini
[Unit]
Description=Birdy Detection System (PIR + Camera + ML)
After=network.target redis.service birdy-celery-worker.service

[Service]
Type=simple
User=pi
Group=pi
WorkingDirectory=/home/pi/birdy_project
Environment="PATH=/home/pi/birdy_project/venv/bin"
ExecStart=/home/pi/birdy_project/venv/bin/python manage.py start_birdy
Restart=always
RestartSec=10
StandardOutput=append:/home/pi/birdy_project/logs/start_birdy.log
StandardError=append:/home/pi/birdy_project/logs/start_birdy.log

[Install]
WantedBy=multi-user.target
```

---

## 5. Nginx Configuration (optional, empfohlen)

**Datei:** `/etc/nginx/sites-available/birdy`

```nginx
upstream birdy_gunicorn {
    server 127.0.0.1:8000;
}

server {
    listen 80;
    server_name your-raspberry-pi-ip your-domain.com;

    client_max_body_size 100M;

    # Static files
    location /static/ {
        alias /home/pi/birdy_project/staticfiles/;
        expires 30d;
        add_header Cache-Control "public, immutable";
    }

    # Media files (Videos, Photos)
    location /media/ {
        alias /home/pi/birdy_project/media/;
        expires 7d;
        add_header Cache-Control "public";
    }

    # Proxy to Gunicorn
    location / {
        proxy_pass http://birdy_gunicorn;
        proxy_set_header Host $host;
        proxy_set_header X-Real-IP $remote_addr;
        proxy_set_header X-Forwarded-For $proxy_add_x_forwarded_for;
        proxy_set_header X-Forwarded-Proto $scheme;
        proxy_redirect off;
    }
}
```

**Nginx aktivieren:**

```bash
# Symlink erstellen
sudo ln -s /etc/nginx/sites-available/birdy /etc/nginx/sites-enabled/

# Default Site deaktivieren (optional)
sudo rm /etc/nginx/sites-enabled/default

# Nginx testen und neu laden
sudo nginx -t
sudo systemctl reload nginx
sudo systemctl enable nginx
```

---

## 6. Installation & Aktivierung

### Service Files installieren

```bash
# Service Files kopieren
sudo cp ~/birdy_project/systemd/*.service /etc/systemd/system/

# Systemd neu laden
sudo systemctl daemon-reload

# Services aktivieren (Auto-Start beim Boot)
sudo systemctl enable redis-server
sudo systemctl enable birdy-celery-worker
sudo systemctl enable birdy-celery-beat
sudo systemctl enable birdy-gunicorn
sudo systemctl enable birdy-detection
sudo systemctl enable nginx

# Services starten
sudo systemctl start redis-server
sudo systemctl start birdy-celery-worker
sudo systemctl start birdy-celery-beat
sudo systemctl start birdy-gunicorn
sudo systemctl start birdy-detection
sudo systemctl start nginx
```

### Status überprüfen

```bash
# Alle Services prüfen
sudo systemctl status birdy-celery-worker
sudo systemctl status birdy-celery-beat
sudo systemctl status birdy-gunicorn
sudo systemctl status birdy-detection
sudo systemctl status nginx

# Logs anzeigen
sudo journalctl -u birdy-detection -f
sudo journalctl -u birdy-gunicorn -f
tail -f ~/birdy_project/logs/birdy.log
```

---

## 7. Hardware testen

Vor dem Produktiv-Start sollten alle Sensoren getestet werden.

### Vorbereitung

```bash
cd ~/birdy_project
source venv/bin/activate
```

### PIR Bewegungssensor

```bash
# Standard-Test (60 Sekunden, Ctrl+C zum Beenden)
python manage.py test_pir

# Längerer Test
python manage.py test_pir --duration 120
```

Zeigt jede Zustandsänderung (Bewegung erkannt / keine Bewegung) mit Zeitstempel an.

### Kamera

```bash
# Foto + 5s Video aufnehmen
python manage.py test_camera
```

Testdateien werden in `/tmp/birdy_test/` gespeichert.

### Gewichtssensor

```bash
# 10 Messungen mit Kalibrierung
python manage.py test_weight

# Kontinuierliche Messung (Ctrl+C zum Beenden)
python manage.py test_weight --continuous

# Mehr Messungen, schnellerer Intervall
python manage.py test_weight --count 20 --interval 0.5
```

### Gewichtssensor Rohdaten (ohne Filter)

```bash
# 20 Rohdaten-Messungen direkt vom HX711
python manage.py test_weight_raw

# Kontinuierlich
python manage.py test_weight_raw --continuous

# Viele Messungen, schnell
python manage.py test_weight_raw --count 50 --interval 0.2
```

### Waage kalibrieren

```bash
# Interaktive Kalibrierung (Gewicht in Gramm angeben)
python manage.py calibrate_weight --weight 100
```

Ablauf:
1. Waage leer → ENTER → Tare wird gesetzt
2. Bekanntes Gewicht auflegen → ENTER → Kalibrierungsfaktor wird berechnet
3. Kalibrierung wird in `weight_calibration.json` gespeichert

---

## 8. Management Commands

### Services neu starten

```bash
# Einzelne Services
sudo systemctl restart birdy-celery-worker
sudo systemctl restart birdy-celery-beat
sudo systemctl restart birdy-gunicorn
sudo systemctl restart birdy-detection

# Alle Birdy Services
sudo systemctl restart birdy-*
```

### Services stoppen

```bash
# Alle Birdy Services stoppen
sudo systemctl stop birdy-*

# Einzelne Services
sudo systemctl stop birdy-detection
```

### Logs überwachen

```bash
# Live Logs
sudo journalctl -u birdy-detection -f
sudo journalctl -u birdy-gunicorn -f

# Letzte 100 Zeilen
sudo journalctl -u birdy-detection -n 100

# Alle Birdy Services
sudo journalctl -u birdy-* -f
```

---

## 9. Firewall (optional)

```bash
# UFW installieren und konfigurieren
sudo apt-get install -y ufw

# SSH erlauben (WICHTIG!)
sudo ufw allow 22/tcp

# HTTP erlauben
sudo ufw allow 80/tcp

# HTTPS erlauben (falls SSL)
sudo ufw allow 443/tcp

# Firewall aktivieren
sudo ufw enable
sudo ufw status
```

---

## 10. Backup & Wartung

### Datenbank Backup (SQLite)

```bash
# Backup erstellen
cp ~/birdy_project/db.sqlite3 ~/birdy_project/backups/db_$(date +%Y%m%d_%H%M%S).sqlite3

# Automatisches Backup via Cron
crontab -e

# Täglich um 3 Uhr
0 3 * * * cp /home/pi/birdy_project/db.sqlite3 /home/pi/birdy_project/backups/db_$(date +\%Y\%m\%d).sqlite3
```

### Datenbank Backup (PostgreSQL)

```bash
# Backup erstellen
pg_dump -U birdy_user birdy_db > ~/birdy_project/backups/db_$(date +%Y%m%d_%H%M%S).sql

# Automatisches Backup via Cron
0 3 * * * pg_dump -U birdy_user birdy_db > /home/pi/birdy_project/backups/db_$(date +\%Y\%m\%d).sql
```

### Log Rotation

**Datei:** `/etc/logrotate.d/birdy`

```
/home/pi/birdy_project/logs/*.log {
    daily
    missingok
    rotate 14
    compress
    delaycompress
    notifempty
    create 0644 pi pi
    sharedscripts
    postrotate
        systemctl reload birdy-gunicorn > /dev/null 2>&1 || true
    endscript
}
```

---

## 11. Monitoring & Health Checks

### System Status Script

**Datei:** `~/birdy_project/check_status.sh`

```bash
#!/bin/bash
echo "=== Birdy System Status ==="
echo ""

services=("redis-server" "birdy-celery-worker" "birdy-celery-beat" "birdy-gunicorn" "birdy-detection" "nginx")

for service in "${services[@]}"; do
    if systemctl is-active --quiet "$service"; then
        echo "✓ $service is running"
    else
        echo "✗ $service is NOT running"
    fi
done

echo ""
echo "=== Disk Usage ==="
df -h /home/pi/birdy_project/media

echo ""
echo "=== Memory Usage ==="
free -h

echo ""
echo "=== CPU Temperature ==="
vcgencmd measure_temp
```

```bash
chmod +x ~/birdy_project/check_status.sh
```

---

## 12. Troubleshooting

### Services starten nicht

```bash
# Detaillierte Logs anzeigen
sudo journalctl -xe -u birdy-detection

# Permissions prüfen
ls -la /home/pi/birdy_project/logs/

# Manuell testen
cd ~/birdy_project
source venv/bin/activate
python manage.py start_birdy
```

### Nginx zeigt 502 Bad Gateway

```bash
# Gunicorn läuft?
sudo systemctl status birdy-gunicorn

# Gunicorn Logs prüfen
tail -f ~/birdy_project/logs/gunicorn_error.log

# Nginx Error Log
sudo tail -f /var/log/nginx/error.log
```

### Celery Tasks werden nicht ausgeführt

```bash
# Redis läuft?
redis-cli ping

# Celery Worker Status
sudo systemctl status birdy-celery-worker

# Registrierte Tasks anzeigen
cd ~/birdy_project
source venv/bin/activate
celery -A birdy_config inspect registered
```

---

## 13. Updates & Deployment

```bash
# Code aktualisieren (Git)
cd ~/birdy_project
git pull

# Dependencies aktualisieren
source venv/bin/activate
pip install -r requirements.txt

# Datenbank migrieren
python manage.py migrate

# Static Files aktualisieren
python manage.py collectstatic --noinput

# Services neu starten
sudo systemctl restart birdy-*
```

---

## Zusammenfassung

**Produktiv-Setup Checklist:**

- [ ] PostgreSQL installiert und konfiguriert (optional)
- [ ] Gunicorn installiert
- [ ] Production Settings erstellt (`settings_production.py`)
- [ ] Static Files gesammelt (`collectstatic`)
- [ ] Systemd Service Files erstellt
- [ ] Services aktiviert und gestartet
- [ ] Nginx konfiguriert (optional)
- [ ] Firewall konfiguriert
- [ ] Backup-Strategie eingerichtet
- [ ] Log Rotation konfiguriert
- [ ] Monitoring eingerichtet

**URL nach Installation:**

- Mit Nginx: `http://your-raspberry-pi-ip/`
- Ohne Nginx: `http://your-raspberry-pi-ip:8000/`

**Wichtige Befehle:**

```bash
# Status prüfen
~/birdy_project/check_status.sh

# Services neu starten
sudo systemctl restart birdy-*

# Logs anzeigen
sudo journalctl -u birdy-detection -f
```

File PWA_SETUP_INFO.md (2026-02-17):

# PWA Setup - Birdy auf Android Homescreen

## ✅ Was wurde erstellt?

### 1. PWA Manifest (`static/manifest.json`)
- Definiert App-Name, Icons, Farben
- Ermöglicht "Add to Homescreen" auf Android/iOS

### 2. App Icons (10 Stück in `static/icons/`)
- **Roter Vogel** auf lila-blauem Hintergrund (#667eea)
- Verschiedene Größen für alle Devices:
  - 72x72, 96x96, 128x128, 144x144, 152x152
  - 192x192, 384x384, 512x512 (Android)
  - 180x180 (apple-touch-icon für iOS)
  - 32x32 (favicon)

### 3. Aktualisiertes Template (`templates/base.html`)
- PWA Manifest Link
- Favicon Links
- Apple Touch Icon
- Theme Color Meta-Tags
- SEO Description

## 🚀 Nächste Schritte

### Development (sofort testen):

```bash
# Static Files sammeln
python manage.py collectstatic --noinput

# Django Server neu starten
./stop_dev.sh
./start_dev.sh
```

### Production:

```bash
# Static Files sammeln
python manage.py collectstatic --noinput --settings=birdy_config.settings_production

# Gunicorn neu starten
sudo systemctl restart birdy-gunicorn
```

## 📱 Auf Android installieren

### Chrome/Edge (Android):

1. Öffne Birdy-Website auf dem Handy
2. Tippe auf **⋮ (Menü)** → **"Zum Startbildschirm hinzufügen"**
3. Bestätige den App-Namen "Birdy"
4. ✅ Rotes Vogel-Icon erscheint auf dem Homescreen!

### Safari (iOS):

1. Öffne Birdy-Website auf dem iPhone
2. Tippe auf **Teilen-Symbol** (Pfeil nach oben)
3. Scroll zu **"Zum Home-Bildschirm"**
4. Bestätige
5. ✅ Icon erscheint auf dem Homescreen!

## 🎨 Icons anpassen

Falls du das Icon-Design ändern möchtest:

```bash
# Icons neu generieren:
python generate_icons.py

# Static Files neu sammeln:
python manage.py collectstatic --noinput
```

Das `generate_icons.py` Script erstellt einen **roten Vogel** auf lila-blauem Hintergrund.

### Farben ändern:

Editiere `generate_icons.py`:
```python
BACKGROUND_COLOR = "#667eea"  # Header-Farbe (lila-blau)
BIRD_COLOR = "#ff4444"        # Vogel-Farbe (rot)
```

## 🔍 Testen

### PWA Manifest testen:

1. Chrome DevTools öffnen (F12)
2. **Application** Tab
3. **Manifest** → Prüfe ob alle Icons geladen werden
4. **Service Workers** → (optional für Offline-Support)

### Icons testen:

Besuche im Browser:
- http://raspberrypi.local:8000/static/manifest.json
- http://raspberrypi.local:8000/static/favicon.ico
- http://raspberrypi.local:8000/static/icons/icon-192x192.png

## 📝 Technische Details

### PWA Eigenschaften:

- **Display:** Standalone (Fullscreen ohne Browser-UI)
- **Orientation:** Portrait (Hochformat)
- **Theme Color:** #667eea (Lila-Blau)
- **Background Color:** #667eea
- **Icons:** Purpose "any maskable" (funktioniert überall)

### Unterstützte Plattformen:

✅ **Android** (Chrome, Edge, Samsung Internet, Firefox)
✅ **iOS** (Safari 11.3+)
✅ **Desktop** (Chrome, Edge)

## 🐛 Troubleshooting

### Icon wird nicht angezeigt auf Android:

1. Prüfe ob `collectstatic` ausgeführt wurde
2. Leere Browser-Cache
3. Prüfe ob manifest.json korrekt geladen wird (DevTools)
4. Prüfe ALLOWED_HOSTS in Production Settings

### Icon hat falsche Farbe:

1. Regeneriere Icons: `python generate_icons.py`
2. Sammle Static Files: `python manage.py collectstatic --noinput`
3. Hard-Refresh im Browser (Ctrl+Shift+R)

### "Add to Homescreen" Option fehlt:

- Chrome/Android: Manifest muss korrekt geladen werden
- iOS/Safari: Nur über Teilen-Menü möglich (kein automatischer Banner)
- HTTPS erforderlich (außer localhost/192.168.x.x)

## ✨ Weitere PWA Features (optional)

Falls du später Offline-Support willst:

1. Service Worker erstellen (`static/sw.js`)
2. In base.html registrieren:
   ```javascript
   <script>
   if ('serviceWorker' in navigator) {
     navigator.serviceWorker.register('/static/sw.js');
   }
   </script>
   ```

3. Cache-Strategie implementieren (Offline-Zugriff auf Bilder/API)

## 🎯 Ergebnis

Nach dem Setup hast du:

✅ Birdy App-Icon mit rotem Vogel auf Android/iOS Homescreen
✅ Fullscreen-Modus beim Start vom Homescreen
✅ Native App-ähnliches Feeling
✅ Theme-Farbe passt zum Design (#667eea)

Viel Spaß mit der Birdy PWA! 🐦

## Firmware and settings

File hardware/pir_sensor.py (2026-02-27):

"""
PIR Motion Sensor Interface - Native lgpio Implementation
Raspberry Pi 5 optimiert - verwendet lgpio direkt ohne gpiozero
"""
import logging
import threading
import time

from django.conf import settings
from django.utils import timezone

try:
    import lgpio
except ImportError:
    raise ImportError("lgpio library not found. Install with: pip install lgpio")

logger = logging.getLogger('birdy')


class PIRSensorController:
    """Controller für PIR Bewegungssensor - Native lgpio Implementation"""

    def __init__(self):
        self.pin = settings.BIRDY_SETTINGS['PIR_SENSOR_PIN']
        self.chip_handle = None
        self.is_initialized = False
        self.last_motion_time = None
        self.motion_active = False

        # Cooldown um false triggers zu vermeiden
        # Ignoriere Bewegungen wenn letzte Bewegung < 60 Sekunden her ist
        self.min_motion_interval = 10  # Sekunden

        # Callbacks die bei Events aufgerufen werden
        self.on_motion_callbacks = []
        self.on_no_motion_callbacks = []

        # Polling Thread für GPIO Monitoring
        self._monitor_thread = None
        self._monitor_running = False
        self._last_gpio_state = 0

    def initialize(self):
        """Initialisiere PIR Sensor mit lgpio"""
        try:
            # Öffne GPIO Chip (gpiochip0 auf Raspberry Pi 5)
            self.chip_handle = lgpio.gpiochip_open(0)
            logger.info(f"GPIO chip opened successfully (handle={self.chip_handle})")

            # Konfiguriere GPIO Pin als Input mit Pull-Down
            # Flags: LGPIO_SET_PULL_DOWN = 4
            lgpio.gpio_claim_input(self.chip_handle, self.pin, lgpio.SET_PULL_DOWN)
            logger.info(f"PIR sensor GPIO{self.pin} claimed as input with pull-down")

            # Lese initialen Zustand
            self._last_gpio_state = lgpio.gpio_read(self.chip_handle, self.pin)
            logger.info(f"Initial GPIO state: {self._last_gpio_state}")

            self.is_initialized = True

            # Warte auf Sensor Warmup (ca. 30-60 Sekunden)
            logger.info("PIR sensor warming up (30s)...")
            time.sleep(30)

            # Starte Monitoring Thread
            self._monitor_running = True
            self._monitor_thread = threading.Thread(target=self._monitor_gpio, daemon=True)
            self._monitor_thread.start()

            logger.info("PIR sensor ready (monitoring thread started)")

            return True

        except Exception as e:
            logger.error(f"Failed to initialize PIR sensor: {e}")
            self.is_initialized = False
            if self.chip_handle is not None:
                try:
                    lgpio.gpiochip_close(self.chip_handle)
                except Exception:
                    pass
                self.chip_handle = None
            return False

    def _monitor_gpio(self):
        """
        Background Thread der kontinuierlich GPIO Pin überwacht
        Erkennt Zustandsänderungen (LOW->HIGH, HIGH->LOW)
        """
        logger.debug("PIR GPIO monitoring thread started")

        motion_start_time = None

        while self._monitor_running:
            try:
                # Lese aktuellen GPIO Zustand
                current_state = lgpio.gpio_read(self.chip_handle, self.pin)

                # Zustandsänderung erkannt
                if current_state != self._last_gpio_state:
                    timestamp = timezone.now()

                    if current_state == 1:
                        # LOW -> HIGH (Bewegung erkannt)
                        logger.debug(f"PIR: GPIO {self.pin} went HIGH (motion)")
                        motion_start_time = time.time()
                        self._handle_motion_detected(timestamp, current_state)

                    else:
                        # HIGH -> LOW (Bewegung beendet)
                        logger.debug(f"PIR: GPIO {self.pin} went LOW (no motion)")
                        duration = None
                        if motion_start_time:
                            duration = time.time() - motion_start_time
                        self._handle_no_motion(timestamp, current_state, duration)
                        motion_start_time = None

                    self._last_gpio_state = current_state

                # Poll alle 50ms (20 Hz)
                time.sleep(0.05)

            except Exception as e:
                logger.error(f"Error in PIR monitoring thread: {e}")
                time.sleep(0.5)  # Längere Pause bei Fehler

        logger.debug("PIR GPIO monitoring thread stopped")

    def _handle_motion_detected(self, timestamp, gpio_state):
        """Interner Handler für Bewegungserkennung"""
        logger.debug(f"PIR: _handle_motion_detected called, GPIO state={gpio_state}")

        # Cooldown Check: Ignoriere Trigger wenn zu kurz nach letztem Trigger
        if self.last_motion_time is not None:
            time_since_last = (timestamp - self.last_motion_time).total_seconds()
            if time_since_last < self.min_motion_interval:
                logger.warning(f"PIR: Motion detected but IGNORED (cooldown: {time_since_last:.1f}s < {self.min_motion_interval}s, gpio={gpio_state})")
                return

        self.motion_active = True
        self.last_motion_time = timestamp

        logger.info(f"PIR: Motion detected! (gpio={gpio_state})")

        # Speichere Event in DB
        from sensors.models import PIREvent
        event = PIREvent.objects.create(event_type='triggered')

        # Rufe alle registrierten Callbacks auf
        for callback in self.on_motion_callbacks:
            try:
                callback(event)
            except Exception as e:
                logger.error(f"Error in motion callback: {e}")

    def _handle_no_motion(self, timestamp, gpio_state, duration):
        """Interner Handler für Ende der Bewegung"""
        logger.debug(f"PIR: _handle_no_motion called, GPIO state={gpio_state}")

        if not self.motion_active:
            return

        self.motion_active = False

        logger.info(f"PIR: No motion (duration: {duration:.2f}s, gpio={gpio_state})")

        # Speichere Event in DB
        from sensors.models import PIREvent
        event = PIREvent.objects.create(
            event_type='cleared',
            duration_seconds=duration
        )

        # Rufe alle registrierten Callbacks auf
        for callback in self.on_no_motion_callbacks:
            try:
                callback(event)
            except Exception as e:
                logger.error(f"Error in no-motion callback: {e}")

    def register_motion_callback(self, callback):
        """
        Registriere Callback für Bewegungserkennung

        Args:
            callback: Funktion die aufgerufen wird (erhält PIREvent als Parameter)
        """
        if callback not in self.on_motion_callbacks:
            self.on_motion_callbacks.append(callback)
            logger.debug(f"Registered motion callback: {callback.__name__}")
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

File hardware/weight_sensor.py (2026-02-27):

"""
Weight Sensor Interface - HX711 Wägezelle
Verwendet die HX711 Library von tatobari
"""
import logging
import time

from django.conf import settings

logger = logging.getLogger('birdy')

try:
    from hx711 import HX711
except ImportError:
    logger.error("HX711 library not found. Install with: pip install HX711")
    HX711 = None

NUMBER_HW_MEASUREMENTS = 5

class WeightSensor:
    """Interface für HX711 Wägezelle"""

    def __init__(self):
        self.dt_pin = settings.BIRDY_SETTINGS['WEIGHT_SENSOR_DT_PIN']
        self.sck_pin = settings.BIRDY_SETTINGS['WEIGHT_SENSOR_SCK_PIN']
        self.hx711 = None
        self.calibration_factor = 1.0
        self.tare_offset = 0
        self.is_initialized = False
        # Gleitender Durchschnitt zur Glättung
        self.weight_history = []
        self.history_size = 5  # Letzte 5 Messungen speichern
        # Automatische Drift-Kompensation
        self.zero_readings = []  # Messungen wenn Waage leer ist
        self.stable_readings = []  # Stabile Messungen (unabhängig vom Gewicht)
        self.last_weight_stable = None  # Letztes stabiles Gewicht
        self.last_drift_compensation = time.time()
        self.drift_compensation_interval = 3600  # Alle 60 Minuten prüfen

    def initialize(self):
        """Initialisiere HX711 Sensor"""
        if HX711 is None:
            logger.error("HX711 library not available")
            return False

        try:
            logger.info(f"Pins used for weight sensor pins DT:{self.dt_pin}, SCK:{self.sck_pin}")
            self.hx711 = HX711(dout_pin=self.dt_pin, pd_sck_pin=self.sck_pin, gain=128, channel='A')

            # Reset sensor
            result = self.hx711.reset()
            if result:			# you can check if the reset was successful
                logger.info("Reset of weight sensor successfull")
            else:
                logger.error("Reset of weight sensor not successfull")

            time.sleep(0.5)

            self.is_initialized = True
            logger.info(f"Weight sensor initialized on pins DT:{self.dt_pin}, SCK:{self.sck_pin}")
            return True

        except Exception as e:
            logger.error(f"Failed to initialize weight sensor: {e}")
            self.is_initialized = False
            return False

    def tare(self, samples=10):
        """Tara - Nullstellung des Sensors"""
        if not self.is_initialized:
            logger.warning("Sensor not initialized, attempting to initialize...")
            if not self.initialize():
                return False

        try:
            logger.info("Performing tare...")

            # Mehrere Messungen für Durchschnitt
            readings = []
            for i in range(samples):
                try:
                    val = self.hx711.get_raw_data(NUMBER_HW_MEASUREMENTS)
                    if val is not False:  # HX711 gibt False bei Fehler zurück
                        for j in range (NUMBER_HW_MEASUREMENTS):
                            readings.append(val[j])
                    time.sleep(0.1)
                except Exception as e:
                    logger.warning(f"Reading {i} failed: {e}")
                    continue

            if not readings:
                logger.error("No valid readings during tare")
                return False

            self.tare_offset = sum(readings) / len(readings)
            logger.info(f"Tare completed: offset = {self.tare_offset:.2f} (from {len(readings)} readings)")
            return True

        except Exception as e:
            logger.error(f"Tare failed: {e}")
            return False

    def calibrate(self, known_weight_grams, samples=10):
        """
        Kalibrierung mit bekanntem Gewicht

        Args:
            known_weight_grams: Bekanntes Kalibriergewicht in Gramm
            samples: Anzahl Messungen für Durchschnitt
        """
        if not self.is_initialized:
            logger.warning("Sensor not initialized, attempting to initialize...")
            if not self.initialize():
                return False

        try:
            # Erst tarieren (ohne Gewicht)
            print("\n=== Wägezellen Kalibrierung ===")
            print("Schritt 1: Tara (Nullstellung)")
            print("Bitte alle Gewichte entfernen und ENTER drücken...")
            input()

            if not self.tare(samples):
                print("✗ Tara fehlgeschlagen!")
                return False

            print("✓ Tara abgeschlossen\n")

            # Dann mit bekanntem Gewicht messen
            print(f"Schritt 2: Kalibrierung mit {known_weight_grams}g")
            print(f"Bitte {known_weight_grams}g auflegen und ENTER drücken...")
            input()

            print(f"Messe {samples} Werte...")
            readings = []
            for i in range(samples):
                try:
                    val = self.hx711.get_raw_data(NUMBER_HW_MEASUREMENTS)
                    if val is not False:
                        for j in range (NUMBER_HW_MEASUREMENTS):
                            readings.append(val[j] - self.tare_offset)
                    time.sleep(0.2)
                except Exception as e:
                    logger.warning(f"Reading {i} failed: {e}")
                    continue

            if not readings:
                logger.error("No valid readings during calibration")
                print("✗ Keine gültigen Messungen!")
                return False

            avg_reading = sum(readings) / len(readings)
            self.calibration_factor = avg_reading / known_weight_grams

            logger.info(f"Calibration completed: factor = {self.calibration_factor:.6f}")
            print("\n✓ Kalibrierung abgeschlossen!")
            print(f"Kalibrierungsfaktor: {self.calibration_factor:.6f}")
            print(f"Durchschnittswert: {avg_reading:.2f}")
            print(f"Erwartetes Gewicht: {known_weight_grams}g")
            print(f"Berechnetes Gewicht: {avg_reading / self.calibration_factor:.2f}g")

            # Speichere Kalibrierung
            self._save_calibration()

            return True

        except Exception as e:
            logger.error(f"Calibration failed: {e}")
            print(f"✗ Kalibrierung fehlgeschlagen: {e}")
            return False

    def read_weight_grams(self, samples=10):
        """
        Lese aktuelles Gewicht in Gramm mit verbesserter Filterung

        Args:
            samples: Anzahl Messungen für Durchschnitt (Standard: 10)

        Returns:
            float: Gewicht in Gramm oder None bei Fehler
        """
        if not self.is_initialized:
            logger.warning("Sensor not initialized")
            return None
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

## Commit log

2026-02-17 Initial commit: Birdy Smart Bird Feeder
    Raspberry Pi-based smart bird feeder with:
    - Django web app with REST API
    - Bird detection via PIR sensor, camera & TFLite ML model
    - HX711 weight sensor integration
    - Home Assistant MQTT integration
    - Celery task queue for background processing
    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
    [labels.csv]
2026-02-17 Add Home Assistant dashboard with MQTT camera and video link
    - Add MQTT camera entity (birdy_last_visitor) publishing photo as binary
    - Extend species sensor with json_attributes_topic for photo/video URLs
    - Publish last detection data with retain flag in periodic status task
    - Add BIRDY_BASE_URL setting for full media URLs
    - Add dashboard.yaml reference for HA raw config editor
2026-02-25 Add mechanical construction files for birdhouse enclosure
    3D-printed parts (STL/G-code) and CNC-milled wood parts (Estlcam/G-code)
    for the complete birdhouse assembly. SketchUp source file included.
    README updated with Mechanical Construction section.
    [back.stl, bar_left.stl, bar_right.stl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]
2026-02-26 Refactor detection: classify first, create DB entries only on valid visit
    - Move DB entry creation (Video, Photo, BirdDetection) after classification
    - Delete video/frame files if no valid bird detected (saves storage)
    - Replace latest.mp4 symlink with file copy (vfat has no symlink support)
    - Simplify post-validation code (remove null-checks, now guaranteed valid)
2026-02-26 Improve frame selection: classify all candidate frames, pick best
    Instead of extracting the middle frame, extract 8 evenly-spaced frames
    from the 4s video and run the TFLite classifier on each. The frame with
    the highest non-background confidence is saved as the detection photo,
    resulting in better-quality bird images.
2026-02-26 Remove redundant single-frame extraction from camera worker
    The worker was extracting a frame after each recording as a legacy
    side effect. Frame selection now happens in the detection service via
    extract_candidate_frames(), so this was wasted work producing orphaned
    .jpg files next to the video.
2026-02-26 Update docs to reflect multi-frame best-frame detection
    - README.md: Detection Pipeline updated (8 frames, best-frame selection)
    - SPECIES_DETECTION_RULES.md: Implementation, examples, and summary updated
    to reflect that invalid detections are never stored in DB
    - CAMERA_ARCHITECTURE.md: Processing time estimate updated (15-20s)
2026-02-27 Add Swiss Mittelland regional species filter
    The global iNaturalist model (964 species) regularly produced implausible
    detections for the Swiss Mittelland: Northern Cardinal, Monk Parakeet,
    Galah, Kea, Ruby-throated Hummingbird, etc.
    New filter restricts classifications to 151 species plausible for the
    Swiss Mittelland. The highest-scoring allowed species wins per frame;
    'background' is always allowed so non-bird frames are still rejected.
    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
2026-02-27 Add statistics page with monthly/yearly charts and tables
    - New /statistics/ route with year/month/species filters
    - Bar chart (visits per month or top species) + doughnut chart (species distribution) via Chart.js CDN
    - KPI cards: total visits, species count, best month, top species
    - Data table: monthly overview or per-species breakdown
    - Navigation link added to base template
2026-02-27 Add Ruff linting and fix 394 code style issues
    - Add ruff.toml config (line-length 120, E/W/F/I/DJ rules, Django patterns excluded)
    - Auto-fix 366 issues: whitespace, import sorting, unused imports, f-strings
    - Fix 11x bare except: → except Exception: (hardware, services, sensors)
    - Fix syntax error in ml_models/translate_birds.py (split string literal)
    - Remove unused variable current_month in views.py
    - Add noqa comments for intentional Django patterns (star import, E402)
    - Install ruff 0.15.4 in venv
    [calibrate_weight.py, camera.py, camera_worker.py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]
2026-02-28 Fix classifier: apply softmax to model logits for correct probabilities
    - Apply numerically stable softmax (with float32 cast to prevent uint8
    integer overflow) instead of broken scale_factor heuristic
    - Add IGNORED_SPECIES setting (Felsentaube) to treat false-positive
    species like background in the detection workflow
    [settings.py]
2026-02-28 Add examples folder with sample detection photos and video
2026-03-19 Add dynamic PIR-based recording, BirdSizeDetector, and visit deduplication
    - Dynamic video recording: rpicam-vid runs while PIR is HIGH (max 30s),
    stops 3s after PIR goes LOW. Records to raw H.264, muxed to MP4 via
    ffmpeg (-f h264 -r 15) to avoid moov atom issues on SIGTERM.
    - Proportional frame extraction: 2fps, min 8 frames (e.g. 15s → 30 frames)
    - BirdSizeDetector (SSD MobileNet V2 COCO): filters frames without a
    sufficiently large bird in the feeder ROI (fail-open fallback)
    - Visit deduplication: is_new_visit field on BirdDetection, same species
    within 5 min = continuation, statistics count only new visits
    - Recording lock prevents parallel recordings during active detection
    -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
    [camera.py, camera_worker.py, settings.py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]
